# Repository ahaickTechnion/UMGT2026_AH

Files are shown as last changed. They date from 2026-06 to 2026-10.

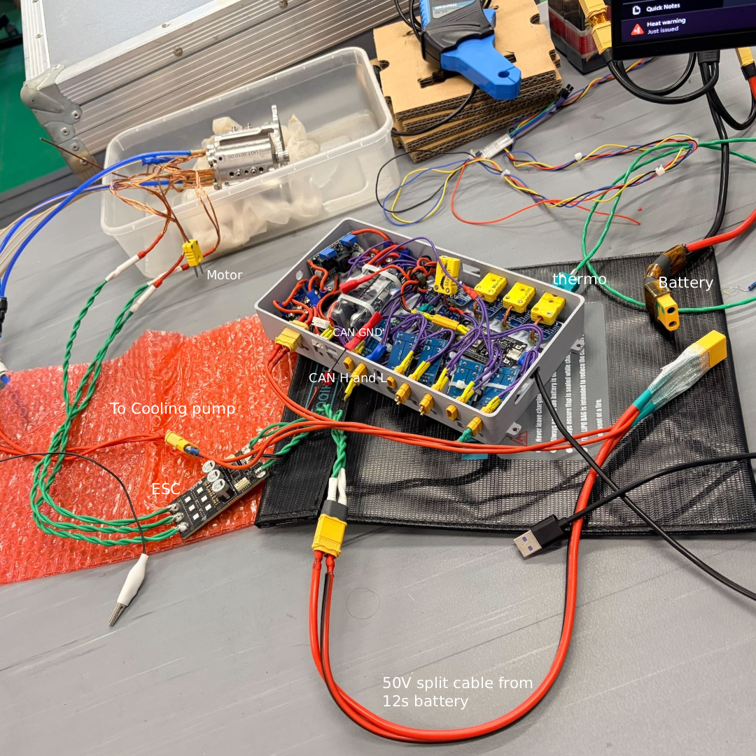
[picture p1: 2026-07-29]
UMGT/02. Documents/Motor setup.png

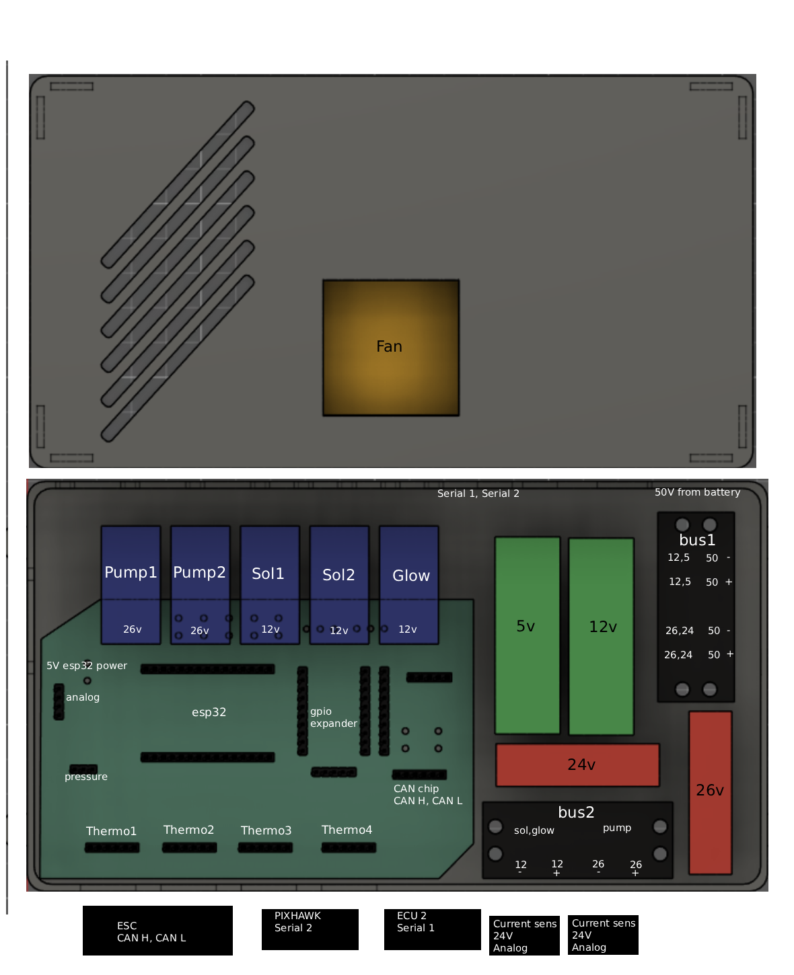
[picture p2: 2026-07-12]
UMGT/02. Documents/wiringdiagram2.png

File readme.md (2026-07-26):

# UMGT ECU 2026

ESP32 DevKitC-32 + ESPSheild carrier board. Firmware lives in `UMGT/src/main.ino.cpp`
(PlatformIO, `pio run -e esp32dev`). Two GUIs:

- `ecu_dashboard.py` → `dist/ECU_Dashboard.exe` — low-level I/O test bench
- `engine_dashboard.py` → `dist/UMGT_Engine.exe` — **engine-run GUI**, ported
  from the LabVIEW `umgt_7thJuly2026.vi` test stand (see `LABVIEW_ANALYSIS.md`)

Build either exe: `pyinstaller --onefile --windowed --name <Name> <file>.py`.

All pin assignments below are verified against the KiCad netlist
(`UMGT/ESPSheild-KiCAD/ESPSheild.kicad_pcb`).

---

## ESP32 Pin Summary (verified)

| GPIO | Net | Function |
|---|-----|---|
| GPIO1/3 | U0_TXD/U0_RXD | Serial 1 / USB console → EXE dashboard (J20) |
| GPIO2  | D2 | Extra I/O (J22) |
| GPIO4  | CRX  | **CAN RX** (SN65HVD230, J12) |
| GPIO5  | D5 | Extra I/O (J22) |
| GPIO12 | D12  | X9C digital pot **U/D** (J16) |
| GPIO13 | D13  | X9C digital pot **INC** (J16) |
| GPIO14 | D14  | Extra I/O (J22) |
| GPIO15 | D15  | Piezo / atomizer square wave (J19) |
| GPIO16 | U2_RXD | Serial 2 RX → Pixhawk (J21) |
| GPIO17 | U2_TXD | Serial 2 TX → Pixhawk (J21) |
| GPIO18 | SCK  | SPI clock (thermocouples) |
| GPIO19 | MISO | SPI MISO (thermocouples) |
| GPIO21 | SDA  | I2C data (PCF8575 expander @ 0x20) |
| GPIO22 | SCL  | I2C clock |
| GPIO23 | CTX  | **CAN TX** (no SPI MOSI on this board!) |
| GPIO25/26/27/32/33 | D25… | MOSFET PWM (J9, J10, J11, J7, J8) |
| GPIO34 | D34  | Analog: QNDB6 current sensor A (Battery) |
| GPIO35 | D35  | Analog: QNDB6 current sensor B (Load) |
| GPIO36/39 | VP/VN | Spare analog inputs (J24) |

## Thermocouples (MAX31855, SPI read-only)

Chip selects are **all on the PCF8575 expander** (active LOW).
Expander state bit = 8 + port number (P10 = bit 8 … P17 = bit 15).

| Connector | Net | Expander port | State bit | Channel |
|---|-----|---|---|---|
| J3 | CS1 | P12 | 10 | TC1 — TIT |
| J4 | CS2 | P13 | 11 | TC2 — EGT |
| J5 | CS3 | P14 | 12 | TC3 — Bearing |
| J6 | CS4 | P15 | 13 | TC4 — Coil |

## Digital pot (X9C103S/X9C503S, J16)

| J16 pin | Signal | Driven by |
|---|---|---|
| 1 | GND | — |
| 2 | U/D | GPIO12 |
| 3 | INC | GPIO13 (wiper steps on falling edge) |
| 4 | CS  | Expander P16 (state bit 14, active LOW) |
| 5 | 3.3V | — |

Firmware resets the wiper to position 0 at boot and tracks it 0–99.

## MOSFET outputs (J7–J11, 2-pin GND+signal)

Verified wiring (2026-07-08):

| # | Connector | GPIO | Load |
|---|---|---|---|
| 1 | J7  | 32 | **Glow plug** (on/off) |
| 2 | J8  | 33 | **Solenoid 2** |
| 3 | J9  | 25 | **Solenoid 1** |
| 4 | J10 | 26 | **Fuel pump 2** (KNF 1.4-M) |
| 5 | J11 | 27 | **Fuel pump 1** (KNF 1.4-M) |

PWM: LEDC channels 2–6 (piezo has channel 0 on its own timer), duty 0–10,
shared frequency default 10 kHz.

## CAN / ESC (SN65HVD230, J12 / passthrough J18)

TWAI driver, TX=GPIO23, RX=GPIO4, default **1 Mbps** (DroneCAN standard).
The ESC is a **Hargrave microDRIVE LPi speaking DroneCAN (UAVCAN v0)**.
Firmware decodes:

- `uavcan.equipment.esc.Status` (1034, 10 Hz, multi-frame): RPM, bus voltage,
  bus current, bridge temperature, power %, plus Hargrave's custom 13-bit
  error field (over-temp, over/under-volt, sig loss, saturation, etc.)
- `uavcan.equipment.esc.StatusExtended` (1036, 1 Hz): input/output %,
  motor temperature, status flags

Decoded values stream as `ESC_RPM/ESC_V/ESC_I/ESC_T/ESC_PWR/ESC_ERR/ESC_AGE/
ESC_IN/ESC_OUT/ESC_MT` keys and fill the ESC banner in the exe. `can esc`
prints them on demand with error names spelled out.

ESC control (all repeated at 50 Hz as node 100, array padded to the ESC's
reported index; `can stop` ends any mode with an explicit zero):

- `can duty <-100..100>` — duty cycle via `esc.RawCommand` (1030). Negative
  duty needs the ESC's **Reversible** drive mode (Normal mode clamps to 0).
- `can rpm <setpoint>` — closed-loop RPM via `esc.RPMCommand` (1031); the ESC
  clamps to its configured min/max RPM (needs correct pole-pair setting).
- `can brake <0-100>` — regen braking as negative duty (Reversible mode);
  braking torque is capped by the ESC's bus/phase current-limit settings.

The commanded mode/value streams back as `ESC_CMODE`/`ESC_CVAL` so the exe
always shows what is being commanded. The codec (Status, StatusExtended RX;
RawCommand, RPMCommand TX, negatives included) was verified bit-exact against
the reference `dronecan` python library.

The ECU is also a **dynamic node ID allocation server** (the role an autopilot
normally plays): an ESC with no node ID sends anonymous allocation requests,
the ECU collects its 16-byte unique ID over the 3-stage exchange and grants it
an ID (its preference, else 125). The ECU broadcasts its own NodeStatus at
1 Hz as node 100. Decoded NodeStatus heartbeats and anonymous-request counts
stream as `NS_ID/NS_MODE/NS_HP/NS_UP` and `ANON`, and the exe Bus tile shows
the allocation state (NO ID → NODE n → ESC OK). The allocation wire format
(echo + multi-frame CRC grant) was verified against pydronecan.

## Current sensors (QNDB6 hall, 100A / 5V output)

GPIO34 = Battery, GPIO35 = Load. Default calibration 20 A/V, zero at 0 V
(`current cal <zeroV> <A_per_V>` to adjust). Note: the ESP32 ADC clips at
~3.3 V ≈ 66 A unless a divider is added.

## Expander extra I/O

P00–P07 (state bits 0–7) are broken out on J13/J17 "EXTRA IO EXPAND" and are
controllable with `i2c expander bit <n> on|off`.

---

## Serial command set (115200 baud on USB)

```
status                          full status dump
tc read <1-4|all>               thermocouples (1=TIT 2=EGT 3=Bearing 4=Coil)
tc scan                         probe all 16 expander CS bits (find wiring/CS issues)
tc mode 31855|6675              select thermocouple chip decode
current all|a|b                 current sensors in amps
current cal <zeroV> <A_per_V>   calibration
pot pos|up <n>|down <n>|set <0-99>|reset|store
can [status|esc]                bus status + decoded microDRIVE telemetry
can duty <-100..100>            duty command (RawCommand 1030, 50 Hz)
can rpm <setpoint>              closed-loop RPM (RPMCommand 1031, 50 Hz)
can brake <0-100>               regen brake = negative duty (Reversible mode)
can stop                        stop any ESC command, send zero
can param list                  enumerate all ESC settings (99 on microDRIVE LPi)
can param get|set <NAME> [v]    by name — CASE-SENSITIVE (e.g. BUS_CUR_LIM)
can param geti|seti <idx> [v]   by index (typed automatically after a read)
can save                        persist ESC params to NVM (microDRIVE reboots itself)
can restart                     reboot ESC (clears latched ERROR flags)
can baud <125|250|500|1000> | can send <id> <hex bytes> | can print on|off
mosfet all|<1-5> on|off|duty <0-10>   ·   mosfet freq <hz>
piezo on|off|duty <0-255>|freq <hz>
analog all|vp|vn|a|b            raw ADC + volts
i2c scan | i2c expander set <hex> | i2c expander bit <n> on|off
serial2 send <text>             forward to Pixhawk UART
serial2 baud <rate>             change Serial2 baud (Pixhawk telem is usually 57600)
serial2 hex on|off              hex-dump Serial2 traffic (MAVLink is binary)
stream on|off                   telemetry stream (default 10 Hz)
stream rate <1-50>              stream rate in Hz; TCs sample at a fixed 10 Hz
                                (MAX31855 converts internally every ~100 ms)
```

### Engine control (ported from LabVIEW + designed sequencer)

```
eng start                       auto sequence: PRECHECK→GLOW→SPOOL→IGNITION→WARMUP→RUNNING
eng stop                        normal shutdown: fuel+glow off → COOLDOWN spin → OFF
eng abort | eng reset           immediate kill (latched FAULT) / clear fault
eng manual                      manual mode (direct pump/glow/throttle, failsafes live)
eng status | eng params         status dump / list parameters (PARAM:name=value)
eng set <name> <value>          edit any sequence/limit/PID parameter (live RAM)
eng save | eng defaults         persist params to ECU flash (survives reboot) / clear
gov on|off | gov sp <rpm>       RPM governor (NI PID Advanced form, out 15-100%)
gov gains <kc> <ti_min> <td_min>
thr <0-100>                     manual engine throttle (slew via governor off)
ramp up|down|pause|off          LabVIEW-style throttle ramp; ramp rate <pct/s>
pump <1|2> <0-100>              independent KNF fuel pumps, fine PWM; pump stop
glow on|off                     glow plug on MOSFET M1 (GPIO32)
sol <1|2> on|off                solenoid 1 (M3/GPIO25) / 2 (M2/GPIO33)
fuel cut on|off                 fuel shutoff latch (pumps forced to 0)
```

Failsafes (always active when anything is live, all editable):
TIT/coil/bearing over-temp, overspeed, flameout (lit + fuel + TIT below
floor), ESC telemetry loss, TIT thermocouple loss mid-sequence. Any trip →
everything safe + latched FAULT.

Engine stream keys: `ENG,FLT,GLW,P1,P2,FF,GOV,GSP,THR,FCUT,RMP`; state
transitions and faults print as `ENG:STATE=…` / `ENG:FAULT=…` events.

Actuators: glow=M1(32), sol2=M2(33), sol1=M3(25), pump2=M4(26), pump1=M5(27),
ESC=DroneCAN. Sensors: TC1=TIT, TC2=glow area, TC3=bearing, TC4=coil,
RPM/V/I from ESC.

Stream line format:

```
DATA:TC1=..,TC2=..,TC3=..,TC4=..,I_A=..,I_B=..,AVP=..,AVN=..,POT=..,PZF=..,PZD=..,CANRX=..,M1=..,..,M5=..
```

`HB` is emitted every second as a heartbeat; Pixhawk traffic is bridged to the
console as `[Serial2] …` lines.

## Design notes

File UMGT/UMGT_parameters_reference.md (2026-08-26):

# UMGT Engine Dashboard — Parameter Reference

Two completely separate sets of values reach this GUI, and mixing them up is the
single most common source of confusion:

| | **ECU internal values** | **ESC parameters** |
|---|---|---|
| Who owns them | the ESP32 (UMGT ECU) | the Hargrave microDRIVE LPi |
| How they arrive | `DATA:` stream, 10 Hz | DroneCAN request/response |
| Panel | *ECU Internal Values* | *ESC Parameters (DroneCAN)* |
| Read with | `Read` (from the last DATA frame) | `Get` → `can param get <NAME>` |
| Needs a working CAN bus | no | **yes** — dead while `CANRX=0` |

`THR` is an ECU value, not an ESC parameter. Asking the ESC for it over
DroneCAN gets no reply, because the ESC has never heard of it.

---

## 1. ECU internal values (the `DATA:` frame)

Sources: repo readme (pin table, MOSFET map, CAN section, engine stream keys)
and `_parse_data()` in `engine_dashboard.py`. Entries marked **(?)** are
inferred — the readme names the signal but not its exact semantics. Confirm
those against `UMGT/src/main.ino.cpp` before trusting them for anything
safety-related.

### Engine state machine

| Key | Unit | R/W | Meaning |
|---|---|---|---|
| `ENG` | — | R | Engine state: `OFF` / `PRECHECK` / `GLOW` / `SPOOL` / `IGNITION` / `WARMUP` / `RUNNING` / `COOLDOWN` / `FAULT` / `MANUAL`. Transitions also print as `ENG:STATE=…` |
| `FLT` | — | R | Latched fault code, `NONE` when clear. Set by the failsafes: TIT/coil/bearing over-temp, overspeed, flameout, ESC telemetry loss, TIT thermocouple loss. Clear with `eng reset` / RESET FAULT |
| `ARM` | — | R | ESC armed. `1` = the ESC will act on throttle. The microDRIVE refuses to spin without the arming broadcast |
| `FCUT` | — | R | Fuel-cut latch (`fuel cut on\|off`). `1` = both pumps forced to 0 regardless of demand |
| `RMP` | — | R | Throttle ramp machine: `OFF` / `UP` / `DOWN` / `PAUSE`, stepped at the ramp rate in %/s |

### Commanded outputs — writable

| Key | Unit | Write sends | Meaning |
|---|---|---|---|
| `THR` | % | `thr <v>` | Commanded engine throttle, 0–100 |
| `GOV` | — | `gov on` / `gov off` | RPM governor. `1` = the PID owns the throttle (output clamped 15–100 %) and `GSP` is the target |
| `GSP` | rpm | `gov sp <v>` | Governor RPM setpoint — only meaningful while `GOV=1` |
| `P1` | % | `pump 1 <v>` | Fuel pump 1 duty — KNF 1.4-M on M5 / GPIO27 |
| `P2` | % | `pump 2 <v>` | Fuel pump 2 duty — KNF 1.4-M on M4 / GPIO26 |
| `GLW` | — | `glow on` / `glow off` | Glow plug — M1 / GPIO32 |
| `SOL1` | % | `sol 1 on\|off` | Solenoid 1 — M3 / GPIO25 |
| `SOL2` | % | `sol 2 on\|off` | Solenoid 2 — M2 / GPIO33 |
| `FF` | ml/min | read-only | Fuel flow, derived from pump duty and the `pump1_cal` / `pump2_cal` parameters |

`THR`, `GSP`, `P1` and `P2` act on the engine immediately, so the GUI asks for
confirmation before sending.

### MOSFET raw duties

Duty is the raw LEDC value **0–10**, not a percentage. These are the same five
outputs as `GLW` / `SOL1` / `SOL2` / `P1` / `P2`, seen at the driver level.

| Key | Connector | GPIO | Load |
|---|---|---|---|
| `M1` | J7 | 32 | Glow plug |
| `M2` | J8 | 33 | Solenoid 2 |
| `M3` | J9 | 25 | Solenoid 1 |
| `M4` | J10 | 26 | Fuel pump 2 |
| `M5` | J11 | 27 | Fuel pump 1 |

In the frame you sent, `M3=10` — solenoid 1 sitting at full duty.

### Thermocouples (MAX31855, chip selects on the PCF8575 expander)

| Key | Connector | CS | Meaning |
|---|---|---|---|
| `TC1` | J3 | CS1 / P12 | Turbine inlet temperature (TIT), °C |
| `TC2` | J4 | CS2 / P13 | The readme's pin table calls this **EGT**, the engine section calls it **glow area** — same probe, two names |
| `TC3` | J5 | CS3 / P14 | Bearing temperature, °C |
| `TC4` | J6 | CS4 / P15 | Coil temperature, °C |

Instead of a number these read `nc` (no probe), `open` (open circuit) or
`sgnd` (shorted to ground). Your frame shows `TC1=nc`, `TC2=open`,
`TC3=open`, `TC4=sgnd` — no probes currently connected.

### ESC telemetry over DroneCAN

| Key | Unit | Source |
|---|---|---|
| `ESC_RPM` | rpm | `esc.Status` (1034, 10 Hz) |
| `ESC_V` | V | Bus voltage — also drives the battery % gauge |
| `ESC_I` | A | Bus current |
| `ESC_T` | °C | Bridge temperature |
| `ESC_PWR` | % | Power |
| `ESC_ERR` | — | Hargrave's custom 13-bit error field: over-temp, over/under-volt, signal loss, saturation… `can esc` spells the bits out |
| `ESC_AGE` | — | Age of the newest telemetry; rising means the stream stopped |
| `ESC_IN` | % | Input, from `esc.StatusExtended` (1036, 1 Hz) |
| `ESC_OUT` | % | Output, from StatusExtended |
| `ESC_MT` | °C | Motor temperature, from StatusExtended |
| `ESC_CMODE` | — | What the ECU is commanding: `DUTY` (RawCommand 1030), `RPM` (RPMCommand 1031), `BRAKE`, or `OFF` |
| `ESC_CVAL` | — | The value being sent in that mode, repeated at 50 Hz |
| `CANRX` | — | **Frames received from the ESC.** `0` = nothing arriving |

`CANRX=0` is the master switch for the whole ESC side: no telemetry, no
parameter access, no arming. Check bus wiring, 120 Ω termination at both ends,
bitrate (default 1 Mbps) and ESC power before anything else.

### DroneCAN node allocation

The ECU is the dynamic node-ID allocation server (node 100), the role an
autopilot normally plays.

| Key | Meaning |
|---|---|
| `NS_ID` / `NS_MODE` / `NS_HP` / `NS_UP` | Node ID, mode, health and uptime from a decoded NodeStatus heartbeat |
| `ANON` | Count of anonymous allocation requests — an ESC with no ID asking to be given one |

### Current sensors and analog inputs

| Key | Unit | Meaning |
|---|---|---|
| `I_A` | A | Current sensor **A — Battery**, GPIO34 |
| `I_B` | A | Current sensor **B — Load**, GPIO35 |
| `I_AV` **(?)** | V | Sensor A raw volts |
| `I_BV` **(?)** | V | Sensor B raw volts |
| `AVP` | V | Spare analog input **VP / GPIO36** (`analog vp`) |
| `AVN` | V | Spare analog input **VN / GPIO39** (`analog vn`) |

> **Discrepancy worth resolving.** The readme describes two independent QNDB6
> hall sensors on GPIO34/35 (20 A/V default, ADC clips near 66 A). The GUI's
> Current Sensor Cal panel and the comments in `_parse_data` instead describe a
> single Bourns SSA-2 differential shunt across the same two pins, where `I_AV`
> is the differential voltage and `I_BV` the common-mode (~1.44 V nominal =
> sensor alive). Both can't be right. Your frame shows `I_A` and `I_B`
> identical at −0.205 — consistent with the differential reading, not with two
> independent sensors. Worth confirming which board is fitted, because the
> calibration meaning of `current cal <zeroV> <A_per_V>` differs between them.

### Other on-board hardware

| Key | Unit | Meaning |
|---|---|---|
| `POT` | 0–99 | X9C digital pot wiper position. Reset to 0 at boot; stepped with `pot up\|down\|set` |
| `PZF` | Hz | Piezo / atomizer square-wave frequency — GPIO15 / J19 |
| `PZD` | 0–255 | Piezo / atomizer duty |
| `EXP` **(?)** | — | PCF8575 expander state. That expander also carries every thermocouple chip select, so a bad value here takes the TCs with it |
| `IFAIL` **(?)** | — | Peripheral failure counter, almost certainly the I2C/expander bus |
| `IREC` **(?)** | — | Peripheral recovery counter, paired with `IFAIL` |

> Your frame shows `IFAIL=510` with `IREC=0`. If that is an I2C error count
> that never recovered, it fits the four failed thermocouple reads —
> worth checking whether the expander at 0x20 answers `i2c scan`.

### Pixhawk / MAVLink bridge (Cube Orange, TELEM1 → J21 → Serial2)

| Key | Meaning |
|---|---|
| `PX_OK` | Heartbeat present. `1` = link up |
| `PX_SYS` / `PX_VER` | Autopilot system ID and MAVLink version |
| `PX_RAW` | **Raw bytes on the RX pin.** `0` = nothing wired or wrong baud (telemetry is usually 57600). Check this first |
| `PX_RX` | Messages successfully decoded |
| `PX_BAD` | Checksum failures — non-zero suggests baud mismatch or noise |
| `PX_TX` | Messages sent to the autopilot |
| `PX_HB` | Milliseconds since the last heartbeat |
| `PX_FIX` | GPS fix: 0 none, 1 no fix, 2 = 2D, 3 = 3D, 4 DGPS, 5 RTK float, 6 RTK fixed, 8 static |
| `PX_SATS` | Satellites used in the fix |
| `PX_HDOP` | Horizontal dilution of precision — under 2.0 is healthy |

---

## 2. Engine parameters (`eng params`)

These are the ECU's editable settings — the table on the Engine page, and also
readable and writable by name from the ECU Internal Values panel. They arrive
as `PARAM:name=value` lines in response to `eng params`.

- **Write** sends `eng set <name> <value>`, which changes live RAM only.
- **Save to ECU** then issues `eng save`, which persists to ESP32 flash.
- `eng defaults` clears them back to firmware defaults.

They cover the start sequence (glow temperature and time, spool duty/RPM and
timeout, ignition fuel start/ramp/max, light-off TIT, ignition timeout, warmup
idle RPM), the failsafe limits (TIT/coil/bearing maxima, max RPM, flameout TIT
floor, ESC loss timeout), cooldown behaviour, pump and fuel calibration,
governor PID gains and limits, ramp rate, and battery voltage endpoints. The
full list with labels and units is `PARAM_META` at the top of
`engine_dashboard.py`.

---

## 3. ESC parameters (DroneCAN)

**I can't give you a per-parameter table for these, and I'd be inventing it if
I tried.** The names live inside the Hargrave microDRIVE LPi's own firmware,
not in this repository — the readme only tells us there are about 99 of them
and gives `BUS_CUR_LIM` as an example. Nothing in `engine_dashboard.py`
enumerates them either; the GUI just passes names through to the ECU.

What is documented:

| Button | Command | Notes |
|---|---|---|
| Get | `can param get <NAME>` | Names are **CASE-SENSITIVE** — `BUS_CUR_LIM`, not `bus_cur_lim` |
| Set | `can param set <NAME> <value>` | Live only until saved |
| List all | `can param list` | Enumerates the real set — the only authoritative source |
| Save NVM | `can save` | Persists to the ESC; **the microDRIVE reboots itself afterwards** |
| Restart ESC | `can restart` | Reboots the ESC and clears latched ERROR flags |

The firmware also supports access by index — `can param geti|seti <idx>` —
which the ECU types automatically after a read.

Two constraints worth remembering: nothing in this panel works while
`CANRX=0`, and changes are lost on an ESC power-cycle unless you Save NVM.

**If you run List all and paste the output to me, I'll document every one of
them properly and add the descriptions to the GUI's help.**

---

## In-app help

Both panels now have a **?** button.

- *ECU Internal Values* — with a name in the box, `?` prints that key's
  description, unit and whether it's writable. With the box empty it prints
  the whole table for the keys in the current DATA frame. `Read` also prints a
  one-line reminder under the value.
- *ESC Parameters* — `?` prints how DroneCAN parameter access works and what
  each button sends.

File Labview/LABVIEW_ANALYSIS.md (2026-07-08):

# LabVIEW `umgt_7thJuly2026.vi` — reverse-engineering notes

Extracted with pylabview from `UMGT/Labview/7thJuly2026/D/!!!Main - Alicat MFC
and pwmESC Folder_1/umgt_7thJuly2026.vi` (front panel heap, block diagram
heap, link info). This is the spec for the ECU engine firmware + engine exe.

## What the VI actually is

A **manual turbogenerator test-stand GUI** — parallel while-loops, no
automated start/stop state machine. The operator manually ramps the ESC,
enables fuel, and watches gauges. Sequencing/failsafes must be designed new
for the ECU (they do not exist in the LabVIEW).

## Front panel — engine-relevant controls (with LabVIEW labels)

Readouts:
- Turbine Inlet Temperature [K] — with color-box warning thresholds
- Near Glow plug Temperature [K] — color thresholds
- Bearing Temperature [degC]
- Generator Coil Temperature [degC] — color thresholds
- Shaft Speed [RPM] (from "MotorTone" tone-frequency measurement)
- DC Voltage [V], DC Current [A], DC Power [W], Battery % (color-coded,
  min/max scaling switched by the 1500 W / 300 W mode)
- Compressor Outlet Pressure [Pa] (transducer: P = 16000*V),
  Inlet Pressure Delta [Pa], Atmospheric Pressure, Bias Voltage
- Air Flow Rate [g/s], Propane Fuel Flow Rate [g/s], total fuel flow, p+k
- Equivalence ratios: Overall Eq Ratio, Equivalence Ratio propane,
  Required Eq Ratio Propane, Required Eq Ratio Kero,
  Required Propane Fuel Flow Rate, Propane Flow Rate Setpoint
- Elapsed Time
- Graphs: RPM, Generator Power, Pressure Ratio, Coil Temperature,
  Bronkhorst Flow rate, KNF Pump flow rate, Dispensed Volume (x2)

Controls:
- speed slider (manual ESC throttle), STOP MOTOR, Stop - Actual, STOP CODE
- Ramp Up / Pause / Ramp Down buttons, Ramp Rate [%/sec], Ramp time,
  Max RPM, Ramping mode indicator
- PID CONTROL toggle + PID gains cluster (Kc, Ti min, Td min) + "PID SETP"
- Fuel Shut Off, Track Fuel Flow Rate
- 1500 W / 300 W mode toggle
- Record, save file (CSV logging via Write Delimited Spreadsheet)
- Time to wait [ms] (loop pacing), HT/LT/full (PWM pulse times)
- Tank 3 / Tank 4 level sliders (syringe pumps), RUN/PAUSE pump buttons

Rig hardware being replaced/dropped in the ECU port:
- Alicat MFC (propane), Bronkhorst FLOW-BUS (kero flow), NE-50X syringe
  pumps, DAQmx AI (temps/pressures), DAQmx CO pulse (ESC PWM), SIMLAB PSU.

## Block diagram logic decoded

- **ESC drive**: Throttle % → "% to us" → 1500..2000 µs servo pulse
  ("2000us (full with)", HT/LT counter times), with a slew limiter
  ("limiting to avoid glitching"). ECU equivalent: DroneCAN duty command.
- **PID**: NI `PID Advanced.vi` — enabled by PID CONTROL; gains from the
  cluster; dt (s) from the loop; **output clamped 15%..100% throttle**;
  setpoint wire labeled "PID SETP"; PV is the measured shaft RPM
  (MotorTone), i.e. an RPM governor commanding ESC throttle.
- **Ramping mode**: case machine driven by Ramp Up/Pause/Ramp Down with
  Ramp Rate [%/s] / Ramp time / Max RPM.
- **Air mass flow**: formula node `mdot = 0.702*sqrt(Pin)` for 1500 W mode,
  0.54 for 300 W (comment: "change mdot from 0.702 for 1500W to 0.54 for
  300W"); Pin = compressor outlet pressure.
- **Fuel stoichiometry**: propane AFR constant 15.5 ("changed from 15.67 to
  15.5"); kero AFR separate; required fuel flow = f(target eq ratio, mdot).
  "Track Fuel Flow Rate" makes the fuel setpoint follow the requirement;
  **Fuel Shut Off forces the fuel flow setpoint to zero**.
- **Kero conversion**: ml/min → g/s via density 0.84 ("ml/min to g/s
  (0.84/60)").
- **Pressure cal**: `P = 16000*V`.
- **Warning colors**: case structures recolor TIT / glow-plug temp / coil
  temp / Battery % indicators against thresholds (thresholds live in the
  unparsed dataspace — re-specified as config in the ECU port).
- **Stop - Actual**: user dialog + loop stop. STOP MOTOR zeroes throttle.

## Mapping to the ECU (per Owen's instructions)

| LabVIEW | ECU |
|---|---|
| ESC PWM 1500-2000 µs + MotorTone RPM | DroneCAN duty + esc.Status RPM/V/I/temp |
| DC V/I/P, Battery % | ESC telemetry voltage/current, computed power |
| NE-50X + Bronkhorst + Alicat fuel | 2× KNF 1.4-M pumps on MOSFET PWM (M1, M2?) |
| Glow plug (external PSU, temp readout only) | Glow plug on/off on MOSFET M5 |
| DAQmx thermocouples | 4× MAX31855: TIT, glow-area (EGT), bearing, coil |
| Pressure transducers | not fitted (VP/VN spare analog if added later) |
| 2 solenoids | not in LabVIEW; ECU has M3/M4 spare |
| PID Advanced (RPM→throttle 15-100%) | Same PID on ESP32, gains from exe |
| Manual ops only | + designed auto start/shutdown/failsafe state machine |

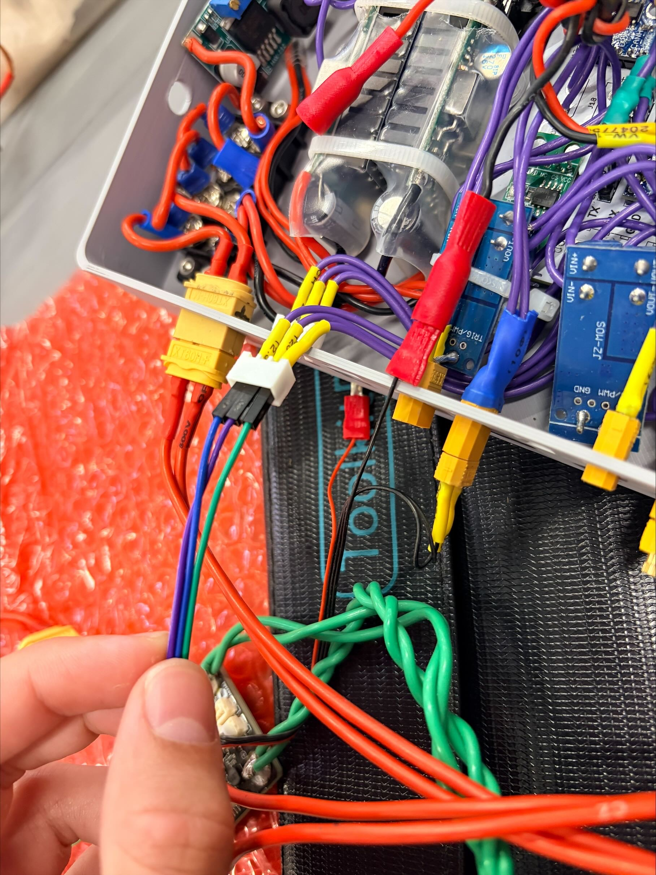
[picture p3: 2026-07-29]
UMGT/02. Documents/Serial Connection.png

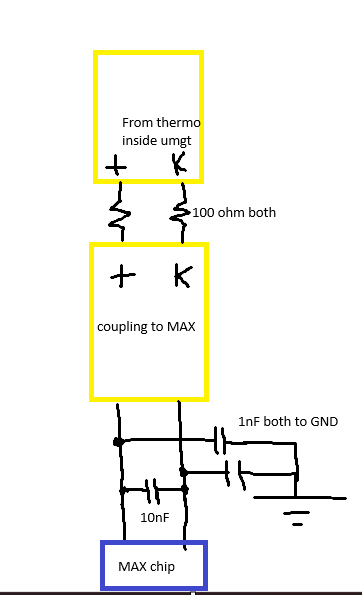
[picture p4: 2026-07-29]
UMGT/02. Documents/MAX chip denoise Diagram.png

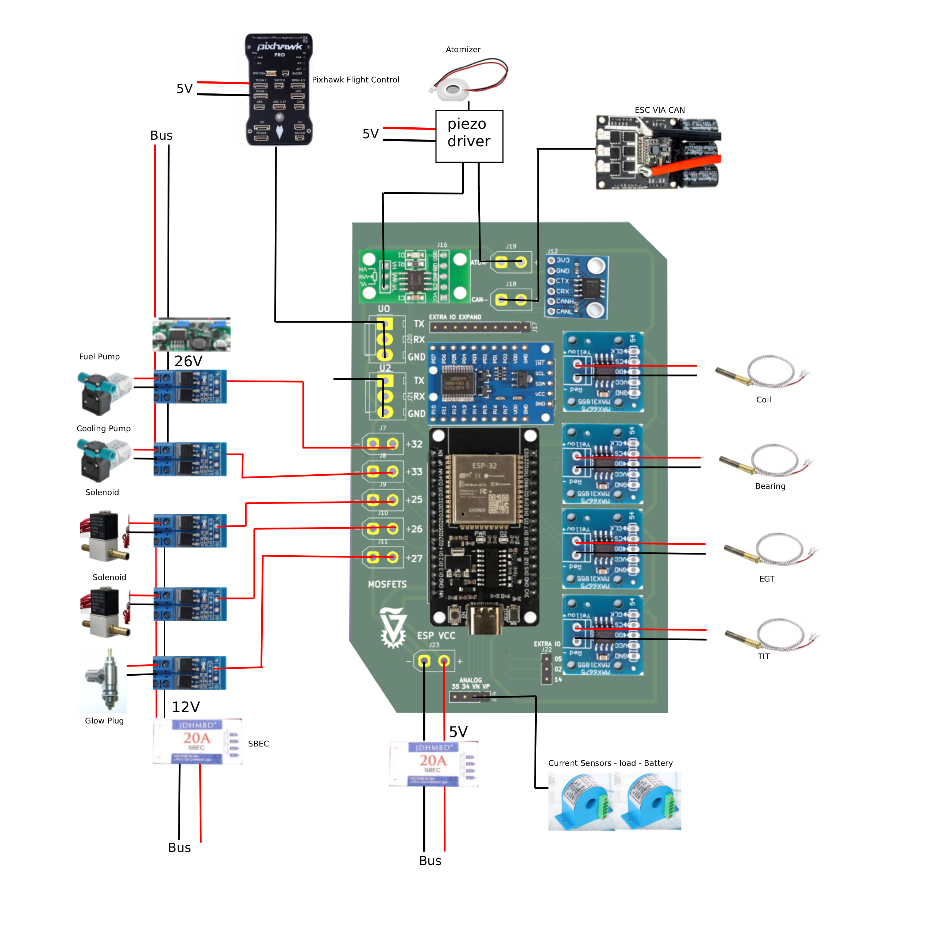
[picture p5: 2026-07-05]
UMGT/02. Documents/Full layout.png

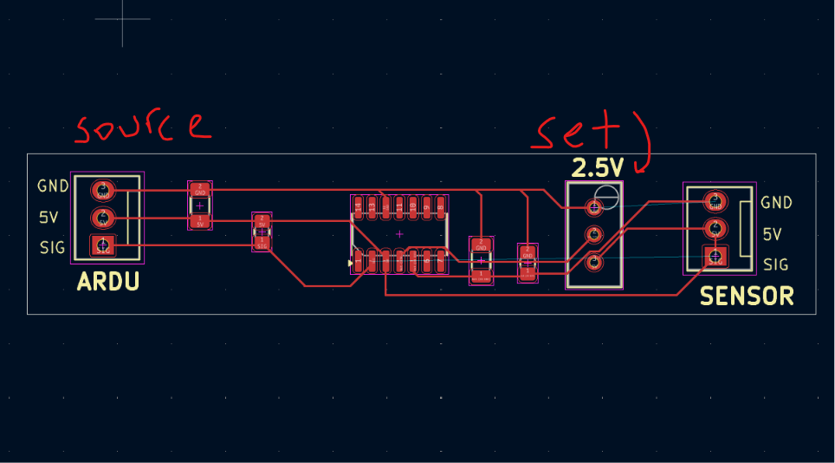
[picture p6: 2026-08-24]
UMGT/00. PCB Boards/RPMSENSOR/sensordiagram1.png

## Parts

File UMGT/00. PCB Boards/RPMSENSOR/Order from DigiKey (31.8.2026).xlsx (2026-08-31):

DigiKey - Shopping Cart
Index | Quantity | Part Number | Manufacturer Part Number | Description | Unit of Measure | Customer Reference | Available | Backorder | Unit Price | Extended Price ILS
1 | 50 | 900-0022013037-ND | 0022013037 | CONN RCPT HSG 3POS 2.54MM |  |  | 50 | 0 | 0.283 | 14.15
2 | 12 | 4518-LM339DRCT-ND | LM339DR | IC COMPARATOR 4CH 14-SOP |  |  | 12 | 0 | 0.437 | 5.24
3 | 12 | 296-1013-1-ND | LM339DR | IC COMPARATOR 4CH 14-SOIC |  |  | 12 | 0 | 0.647 | 7.76
4 | 25 | 311-2.00KCRCT-ND | RC0805FR-072KL | RES 2K OHM 1% 1/8W 0805 |  |  | 25 | 0 | 0.084 | 2.10
5 | 25 | 311-1.00MCRCT-ND | RC0805FR-071ML | RES 1M OHM 1% 1/8W 0805 |  |  | 25 | 0 | 0.084 | 2.10
6 | 25 | 1276-1050-1-ND | CL31B102KBCNNNC | CAP CER 1000PF 50V X7R 1206 |  |  | 25 | 0 | 0.22 | 5.50
7 | 25 | 1276-1017-1-ND | CL31B104KBCNNNC | CAP CER 0.1UF 50V X7R 1206 |  |  | 25 | 0 | 0.22 | 5.50
8 | 12 | 3296W-103LF-ND | 3296W-1-103LF | TRIMMER 10K OHM 0.5W PC PIN TOP |  |  | 12 | 0 | 6.532 | 78.38
9 | 50 | WM4112-ND | 0022272031 | CONN HEADER VERT 3POS 2.54MM |  |  | 50 | 0 | 0.65 | 32.50
10 | 100 | WM1114CT-ND | 0008500113 | CONN 22-30AWG CRIMP TIN |  |  | 100 | 0 | 0.1572 | 15.72
11 | 100 | WM2312-ND | 0008550102 | CONN 22-30AWG CRIMP GOLD |  |  | 100 | 0 | 0.3797 | 37.97

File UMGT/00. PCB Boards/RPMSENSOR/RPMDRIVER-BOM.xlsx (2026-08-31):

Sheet: BOM
Ref | Value | Package / footprint (measured from Gerbers) | Manufacturer | Manufacturer part no. | Qty per board | Qty to order | Notes
U3 | LM339 | SOIC-14, 1.27mm pitch, 3.9mm body | Texas Instruments | LM339DR | 1 | 2 | Quad comparator, open-collector out. Input common-mode range excludes top ~1.5V below V+.
R1 | 2k | 0805 (pads 1.20x1.40mm, 2.00mm centres) | Yageo | RC0805FR-072KL | 1 | 10 | Pull-down on sensor input at U3 pin 5. 1%, 1/8W.
R2 | 1M | 0805 (pads 1.20x1.40mm, 2.00mm centres) | Yageo | RC0805FR-071ML | 1 | 10 | Pull-up on open-collector output. Consider 10k (RC0805FR-0710KL) instead.
C1 | 1nF | 1206 (pads 1.15x1.80mm, 2.95mm centres) | Samsung | CL31B102KBCNNNC | 1 | 10 | Filter on sensor input. 50V X7R; C0G preferred if available.
C2 | 100nF | 1206 (pads 1.15x1.80mm, 2.95mm centres) | Samsung | CL31B104KBCNNNC | 1 | 10 | Supply decoupling at U3. 50V X7R.
RV1 | 10k | Multiturn trimmer, 9.77x5.07mm body, 3 pins in-line 2.54mm, 0.8mm drill | Bourns | 3296W-1-103LF | 1 | 2 | Full divider across 5V/GND, wiper sets threshold. Any value gives 2.5V mid-travel; 10k draws 0.5mA.
J1, J3 | - | 3-pin header 2.54mm, 1.02mm drill, oval pads 2.03x1.73mm, body 7.80x6.05mm | Molex | 22-27-2031 | 2 | 4 | KK-254 friction-lock vertical header. A plain 1x3 2.54mm pin header also fits the holes.
- | - | Mating housing for J1/J3 | Molex | 415304 | 2 | 4 | KK-254 3-circuit crimp housing, one per cable end.
- | - | Crimp terminal for housing | Molex | 08-50-0114 | 6 | 12 | KK-254 female crimp terminal, 3 per housing.
Total lines to order: |  |  |  |  | 16 | 64

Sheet: Board info
Item | Detail
Project | RPMDRIVER (KiCad 8.0.8, gerbers dated 2026-05-20)
Board outline | 73.10 x 14.88 mm, 2 layers, no vias
Drill sizes | 0.80 mm (RV1), 1.02 mm (J1, J3) - both plated
Nets | GND, +5V, sensor (J3.3 -> U3.5), threshold (RV1.2 -> U3.4), SIG (U3.2 -> R2 -> J1.1)
Unused | U3 pins 1, 6, 7, 8, 9, 10, 11, 13, 14 are N/C - three comparators unconnected
Source of values | R1, R2, C1, C2 values come from the schematic, not from the gerbers
Source of packages | Measured from pad apertures, drill file and silkscreen outlines
Open item | J3 has no ground pin: pins 1 and 2 are both on +5V, pin 3 is the sensor signal
Open item | Pad net tags disagree with trace net tags at J3 - PCB rerouted, schematic not updated

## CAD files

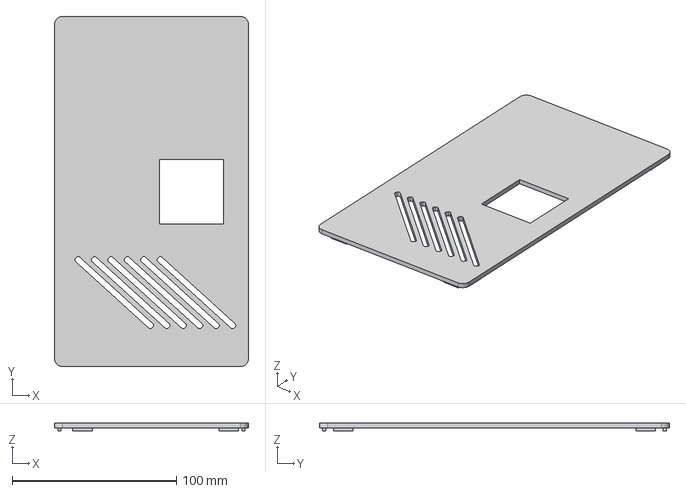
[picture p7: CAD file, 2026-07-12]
UMGT/04. CAD/Owen's Version/BoxtopIGES.iges
118.0 x 213.0 x 5.00 mm

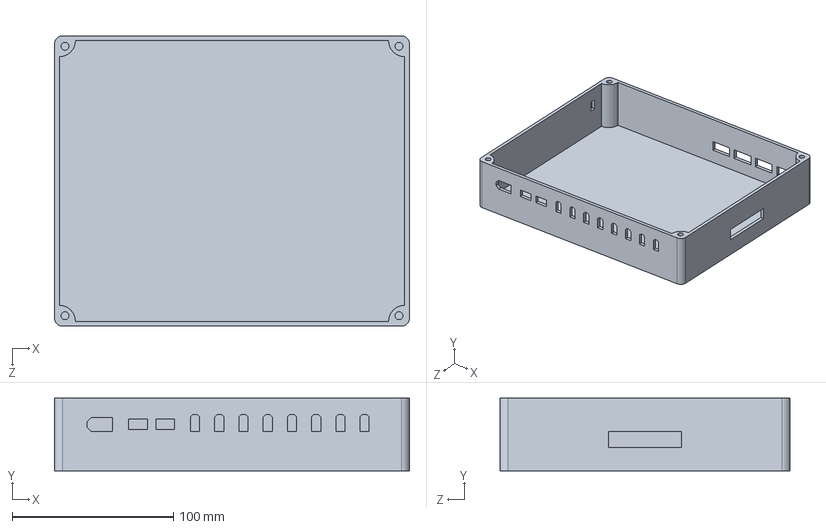
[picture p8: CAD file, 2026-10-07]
UMGT/04. CAD/UMGT-Box-2.SLDPRT
220.0 x 45.0 x 180.0 mm

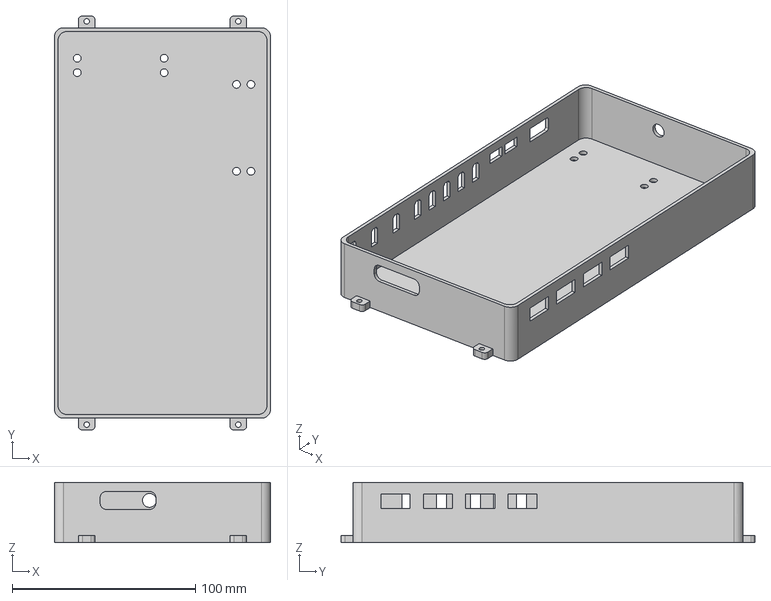
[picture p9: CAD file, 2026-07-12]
UMGT/04. CAD/Owen's Version/BoxbottomIGES.iges
118.0 x 225.9 x 33.0 mm

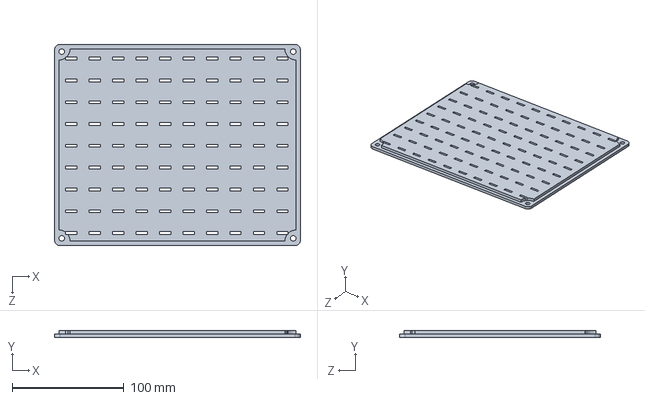
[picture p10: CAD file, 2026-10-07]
UMGT/04. CAD/UMGT-Cover-2.SLDPRT
220.0 x 6.00 x 180.0 mm

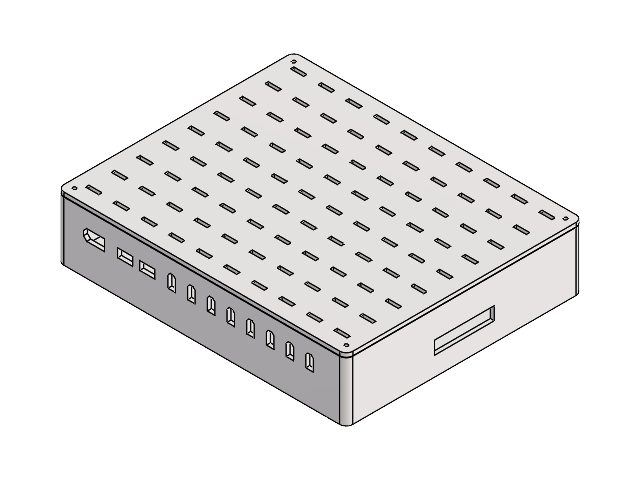
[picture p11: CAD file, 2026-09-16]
UMGT/04. CAD/Assem1.SLDASM
UMGT-Box-2
UMGT-Box-2.2

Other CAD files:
UMGT/04. CAD/UMGT-Box-1.SLDPRT
UMGT/04. CAD/UMGT-Box-2.STL
UMGT/04. CAD/UMGT-Cover-2.STL

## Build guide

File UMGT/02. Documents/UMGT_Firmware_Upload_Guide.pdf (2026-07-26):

UMGT ECU — Firmware Upload Guide | Page 1

# UMGT ECU — Firmware Upload Guide

How to build and upload the ESP32 firmware with PlatformIO

The ECU's brain is an ESP32 board. Everything it does — reading thermocouples, driving pumps, talking to the ESC and Pixhawk — is one program (the firmware) held in a single source file. To change how the ECU behaves you edit that file, build it (compile it on the PC), then upload it to the board over USB. This guide covers exactly that, start to finish. No coding knowledge required — just the steps.

You will need
- The ECU (the ESP32 board on the shield)
- A USB-C data cable (not a charge-only cable)
- A Windows PC with PlatformIO installed (see Section 2)

## 1 Connect the ECU to the computer

The ESP32 board has a USB-C connector on its short edge. Plug USB-C into the ESP32 and the other end into the PC. Power the shield as usual; the USB link is only for programming and the serial console.
- Use a data cable. Many USB cables carry power only — the board will light up but never appear on the PC. If nothing shows up, suspect the cable first.
- The board uses a CH340 USB-to-serial chip. Windows assigns it a COM port number, e.g. COM4 or COM5. You'll need that number.
- If no COM port ever appears, install the CH340 driver (search “CH340 driver Windows”), unplug and replug.

Close the dashboard first
A COM port can only be owned by one program at a time. If the UMGT Engine dashboard (or any serial monitor) is Connected to the board, the upload will fail with “port is busy”. Click Disconnect in the dashboard before uploading — you do not have to close the whole app.

## 2 Set up PlatformIO (one-time)

PlatformIO is the free tool that compiles the code and flashes it to the board. There are two ways to use it — pick one.
Option A — Visual Studio Code (recommended, has buttons)
1 Install Visual Studio Code (free, from Microsoft).
2 Open VS Code → click the Extensions icon on the left (four squares) → search PlatformIO IDE → Install.
3 Let it finish downloading its toolchain, then restart VS Code when it asks. A small PlatformIO (alien head) icon and a blue bottom toolbar appear when it's ready.

Option B — Command line (already installed on this PC)

PlatformIO Core is already installed here, so you can skip Option A if you prefer typing commands. The program is:

C:\Users\owen.maute\.platformio\penv\Scripts\pio.exe

If you type pio in a terminal and it says “not recognized”, use that full path in place of pio in every command below. To install PlatformIO Core on another PC: pip install platformio.

## 3 Where the files live

Everything for the ECU is in the project repo. Two files matter for uploading:

Item | Location / value
Repo root | C:\Users\owen.maute\UMGTECU2026
PlatformIO project | ...\UMGTECU2026\UMGT
Firmware source (edit this) | ...\UMGT\src\main.ino.cpp
Build config | ...\UMGT\platformio.ini

Open the right folder
In VS Code use File → Open Folder and open the UMGT folder — the one that directly contains platformio.ini. If you open the repo root or the wrong level, PlatformIO won't recognise the project and the Build/Upload buttons won't appear.

main.ino.cpp is the entire ECU program — the pin map, the thermocouple/ESC/Pixhawk code, the start sequence, all of it. It is the only file you edit to change behaviour.
platformio.ini tells PlatformIO which board and port to use. It currently reads:

[env:esp32dev]
platform = espressif32
board = esp32dev
framework = arduino
monitor_speed = 115200
upload_speed = 115200
monitor_port = COM4
upload_port = COM4

The only line you may need to change is upload_port (and monitor_port) — see Section 6 on picking the right COM number.

## 4 Verify (build/compile) the code

Always build before you upload. Building compiles the code on the PC and catches mistakes there — a typo caught on the PC is harmless; the same typo flashed to the board could leave the ECU dead. Building does not touch the board, so it's completely safe to do anytime.
In VS Code:
- Click the checkmark (✓) in the blue bottom toolbar, or
- open the PlatformIO sidebar → esp32dev → General → Build.

On the command line (from inside the UMGT folder):

cd C:\Users\owen.maute\UMGTECU2026\UMGT
pio run -e esp32dev
A good build ends with a green SUCCESS and a memory summary like:

RAM: [= ] 7.2% (used 23592 bytes ...)
Flash: [=== ] 28.7% (used 376529 bytes ...)
==================== [SUCCESS] Took 8.0 seconds ====================
If instead you get errors, PlatformIO prints each one with the file and line number (e.g. main.ino.cpp:1234: error: ...). Nothing was sent to the board. Fix the line, build again, repeat until it says SUCCESS.

## 5 Upload to the ECU

Once the build is SUCCESS and the dashboard is disconnected, flash it: In VS Code:
- Click the right-arrow (→) in the blue bottom toolbar, or
- PlatformIO sidebar → esp32dev → General → Upload.

On the command line:

pio run -e esp32dev -t upload
If the board is on a different COM port than platformio.ini lists, name it explicitly (nothing else needs to change):

pio run -e esp32dev -t upload --upload-port COM5
A successful upload scrolls through these stages:
- Connecting........
- Writing at 0x00010000... (12%) … climbing to 100%
- Hash of data verified.
- Hard resetting via RTS pin...

Hash of data verified plus Hard resetting means it worked — the ECU reboots straight into the new firmware. You can reconnect the dashboard now.

## 6 Picking the right COM port

This is the most common gotcha
The ESP32 does not always keep the same COM number. It may come up as COM4 one time and COM5 the next — especially after unplugging and replugging. platformio.ini is set to COM4, but the board is often on COM5. When in doubt, check.

Find the current port two ways:
- Device Manager → Ports (COM & LPT) → look for USB-SERIAL CH340 (COMx). That COMx is your board.

- Or list it from PlatformIO: pio device list.

Then either edit the two ...port = COMx lines in platformio.ini, or just pass --upload-port COMx on the command line for a one-off. (COM1 is not your board — that's a built-in port; ignore it.)

## 7 Troubleshooting

Symptom | Fix
“Could not open COMx, the port is busy” | The dashboard or a serial monitor owns the port. Disconnect it, then upload.
“Failed to connect” / “Timed out waiting for packet header” | Hold the BOOT button on the ESP32 while it says Connecting......, release once Writing starts. Also try a different USB port or cable.
No COM port appears at all | Charge-only cable, or the CH340 driver isn't installed. Swap to a data cable / install the driver, then replug.
Wrong port / uploads to nothing | Board re-enumerated to a different COM number — see Section 6, pass --upload-port.
Build fails with red errors | A code mistake — nothing was flashed. Fix the file:line it names and build again.
Uploads OK but the ECU misbehaves | Confirm you actually edited UMGT\src\main.ino.cpp and that the build was SUCCESS before uploading.
Board keeps dropping off USB mid-session | Usually a power/grounding issue on the rig rather than software — reseat power and USB, avoid unpowered USB hubs.

## 8 Quick reference

Command-line cheat sheet (run these from inside the UMGT folder):

Do this | Command
Go to the project | cd C:\Users\owen.maute\UMGTECU2026\UMGT
Build / verify | pio run -e esp32dev
Upload | pio run -e esp32dev -t upload
Upload to a specific port | pio run -e esp32dev -t upload --upload-port COM5
List connected boards | pio device list
Open the serial console | pio device monitor -b 115200
Clean build files | pio run -e esp32dev -t clean

Golden rule: Disconnect the dashboard → Build (✓) → Upload (→) → wait for “Hash of data verified”.

UMGT ECU project — firmware upload guide. Source of truth: UMGT\src\main.ino.cpp and UMGT\platformio.ini.

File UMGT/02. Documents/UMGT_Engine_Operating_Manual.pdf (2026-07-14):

UMGT Engine Control — Operating Manual | Page 1

# UMGT Engine Control

## Operating Manual & Reference

## Micro gas-turbine ECU — ESP32 firmware + UMGT_Engine dashboard

This manual describes how to connect, configure and operate the UMGT turbine engine control system: every panel, button, parameter and serial command in the UMGT_Engine application, the automatic start sequence, the failsafe logic, and the ESC / fuel / sensor subsystems.

Generated for the UMGT ECU 2026 project

# 1. System Overview

The UMGT engine control system has two halves that talk to each other over a single USB serial link:

■ The ECU (firmware) — an ESP32 DevKitC-32 on a custom carrier board ("ESPSheild"). It reads the sensors, drives the actuators, runs the automatic start/shutdown sequence, the RPM governor and all failsafes, and talks to the ESC over a DroneCAN bus.
■ UMGT_Engine.exe (the GUI) — a Windows dashboard that connects to the ECU over USB, shows live telemetry (charts and gauges), and lets you command the engine, tune parameters and log data. It is a monitor and controller only — all real-time control happens on the ECU, so the engine stays safe even if the PC or USB link drops.
The GUI is modeled on the original LabVIEW turbine test-stand, extended with an automatic sequencer and failsafe supervisor that the LabVIEW did not have.

## 1.1 What the ECU controls and reads

Function | Hardware | Notes
ESC / starter-generator | Hargrave microDRIVE LPi over DroneCAN (CAN 1 Mbps) | Throttle, RPM, brake; reads RPM / voltage / current / temperature
Fuel pump 1 | MOSFET M5 (GPIO27), Hausl ZP25M14F gear pump | PWM, ml/min via calibration curve
Fuel pump 2 | MOSFET M4 (GPIO26) | Independent second fuel pump
Glow plug | MOSFET M1 (GPIO32) | On/off ignition heater
Solenoid 1 | MOSFET M3 (GPIO25) | PWM to ~6 V (configurable duty)
Solenoid 2 | MOSFET M2 (GPIO33) | PWM to ~6 V (configurable duty)
Thermocouples x4 | MAX31855 (SPI), CS via PCF8575 I2C expander | TC1 TIT, TC2 EGT, TC3 Bearing, TC4 Coil
Current sensors x2 | QNDB6 hall sensors on GPIO34 / GPIO35 | Battery / load current
Pixhawk link | Serial2 (GPIO16/17) | Optional telemetry bridge

## 1.2 The USB data link

The ECU streams a compact DATA: line at up to 50 Hz (default 10 Hz) carrying every live value, plus a one-per-second HB heartbeat so the GUI always knows the ECU is alive even when streaming is off. Commands are plain text typed or sent as button presses.

NOTE: The GUI enables the stream automatically when you connect. If you ever see the heartbeat but no live data, type stream on in the terminal — the board is fine, the stream was just off.

# 2. Getting Started

## 2.1 Connecting

1 Plug the ESP32 into USB. Launch UMGT_Engine.exe.
2 Pick the COM port from the drop-down (top-right). If unsure, click the refresh arrow and choose the CH340 port.
3 Click Connect. The ESP32 reboots (~2 s), then the status turns green “Connected” and data begins to flow.
4 Within a few seconds the GUI pulls the saved parameters from the ECU into the parameter panel.

NOTE: The USB-serial port number can change between plug-ins (COM4/COM5/etc.). Just pick whichever port appears. If none appears, unplug and replug the ESP32's USB cable.

## 2.2 The header bar

The header bar, left to right: (1) engine-state chip, (2) COM port, (3) Connect, (4) Record, (5) ABORT ALL.

Control | What it does
Engine state chip | Large label showing the current sequencer state (OFF, MANUAL, PRECHECK, GLOW, SPOOL, IGNITION, WARMUP, RUNNING, COOLDOWN, FAULT).
FAULT text | Appears in red next to the state when a failsafe has tripped, naming the fault.
t = <n> s | Seconds since connecting.
Port drop-down + refresh | Select / rescan the serial port.
Connect / Disconnect | Open or close the serial link.
Record | Start/stop CSV logging of every telemetry field to a file you choose.
ABORT ALL | Emergency stop — immediately cuts fuel, glow, throttle and disarms the ESC, latching a FAULT. Always available.

WARNING: The ABORT ALL button (and the eng abort command) is your emergency stop. It kills every actuator instantly. Know where it is before running the engine.

# 3. The Dashboard, Panel by Panel

The window is arranged in three columns. The left column holds the live charts and the engine-data gauges; the middle column holds the ESC/throttle and fuel controls; the right column holds the sequencer, the parameter editor, the ESC parameter tool and the event terminal.

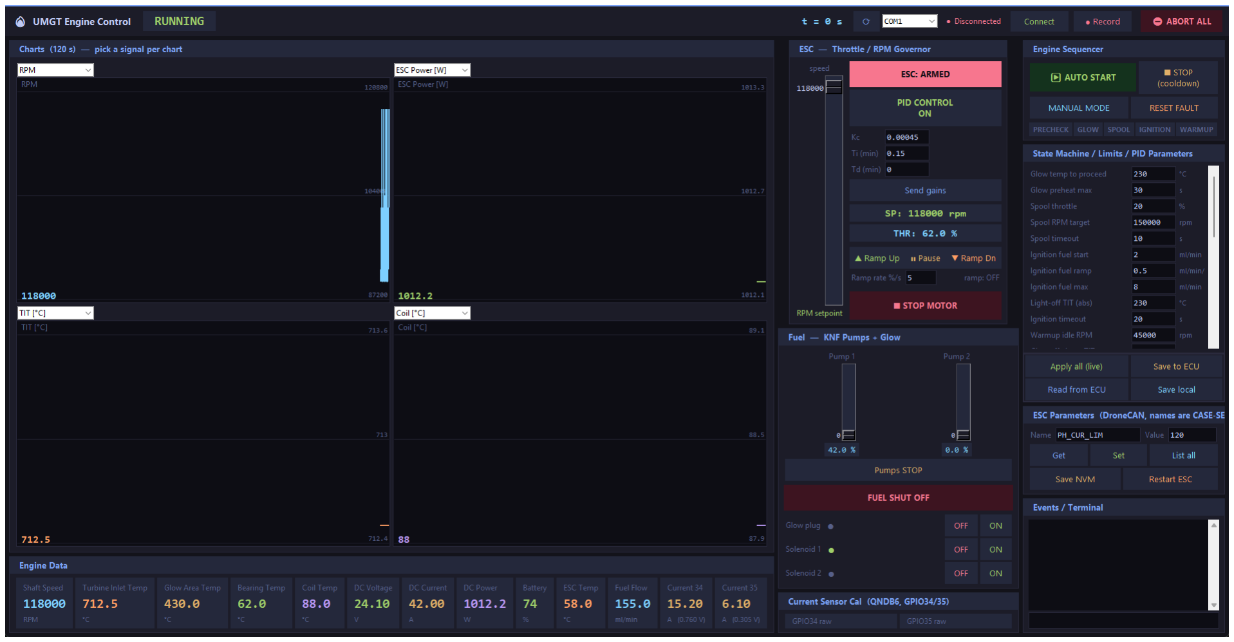
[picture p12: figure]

The full UMGT_Engine dashboard (shown with simulated running data). Left: charts + engine-data gauges. Middle: ESC/throttle and fuel. Right: sequencer, parameters, ESC parameters, terminal.

## 3.1 Charts (top-left)

Four strip charts scroll the last 120 seconds. Each chart has a drop-down at its top-left — pick any signal to plot: RPM, ESC Power, TIT, EGT/Glow, Bearing, Coil, DC Voltage, DC Current, ESC Temp, Battery, Current 34, Current 35, Fuel Flow, or Throttle. Defaults are RPM, ESC Power, TIT and Coil.

NOTE: A chart only draws a signal that has data. If a chart looks blank, the signal it is set to has no valid readings right now (e.g. RPM when the ESC is off, or a thermocouple that reads OPEN). Point it at a live signal.

## 3.2 Engine Data gauges (bottom-left)

A row of numeric gauges with warning colors: Shaft Speed (RPM), Turbine Inlet Temp, Glow Area Temp, Bearing Temp, Coil Temp, DC Voltage, DC Current, DC Power, Battery %, ESC Temp, Fuel Flow (ml/min), and the two hall Current sensors (34 & 35). A temperature gauge turns amber near its limit and red at/over it. A thermocouple with no probe shows OPEN in red.

The two current gauges also show the raw ADC voltage underneath (e.g. “A (1.505 V)”) to help diagnose the sensor.

## 3.3 ESC — Throttle / RPM Governor (middle)

■ ESC: ARMED / DISARMED button — the microDRIVE refuses to spin the motor unless the ECU broadcasts an arming signal. Click to arm (with a confirmation); the button turns red when armed. Arm before commanding throttle; disarm (or ABORT) to make it safe.
■ PID CONTROL button — toggles the RPM governor. Off = the big slider is manual throttle %. On = the slider is an RPM setpoint and the PID holds that RPM.
■ Kc / Ti / Td fields + Send gains — the governor PID gains (Ti and Td in minutes, matching the LabVIEW convention). Type new values and click Send gains.
■ SP / THR readouts — the current RPM setpoint and the throttle % the ECU is actually commanding. ■ Speed slider — the large vertical slider. It sets throttle % (governor off) or RPM setpoint (governor on). It auto-switches labels.
■ Ramp Up / Pause / Ramp Down + Ramp rate — ramps the throttle up or down at the configured %/s instead of jumping.
■ STOP MOTOR — cancels ramp and governor and sets throttle to 0 (stays armed).

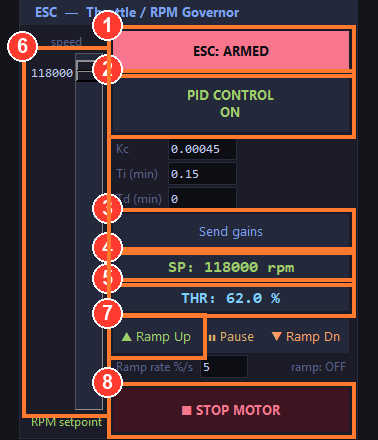
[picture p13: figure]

ESC / Throttle / RPM Governor panel.
1 ESC: ARMED / DISARMED — arm the ESC (red = armed). 2 PID CONTROL — toggle the RPM governor.
3 Send gains — push the Kc / Ti / Td fields above it.
4 SP — current RPM setpoint.
5 THR — throttle % the ECU is commanding.
6 Speed slider — throttle % (governor off) or RPM setpoint (governor on). 7 Ramp Up / Pause / Ramp Down — ramp the throttle at the set rate.
8 STOP MOTOR — throttle to 0 (stays armed).

## 3.4 Fuel — Pumps + Glow + Solenoids (middle)

■ Pump 1 / Pump 2 sliders — set each fuel pump's PWM duty 0–100%. Fuel flow is shown in ml/min via the pump calibration curve.

■ Pumps STOP — both pumps to zero.
■ FUEL SHUT OFF — a latch that forces both pumps to 0 and blocks them until released. Turns dark red when engaged.
■ Glow plug ON / OFF with a status lamp.
■ Solenoid 1 / Solenoid 2 ON / OFF with lamps. “On” drives the MOSFET at the Solenoid-ON-duty parameter (default 50% ≈ 6 V on a 12 V bus).

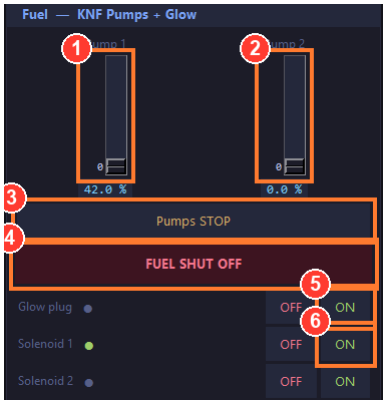
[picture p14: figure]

Fuel panel: pumps, glow plug, solenoids.
1 Pump 1 slider — fuel pump 1 duty (flow shown in ml/min). 2 Pump 2 slider — fuel pump 2 duty.
3 Pumps STOP — both pumps to zero.
4 FUEL SHUT OFF — latch that forces both pumps to 0.
5 Glow plug ON / OFF — with status lamp.
6 Solenoid 1 / 2 ON / OFF — drives the coil at ~6 V.

## 3.5 Current Sensor Cal (middle)

Live raw voltage for GPIO34 and GPIO35, plus calibration controls: a Zero V and A/V field with Apply; Zero now (@0A) which captures the present voltage as the zero point; preset buttons Uni 100A/5V and Bipolar ±100A/5V; and a Turns field for the multi-turn trick (pass the wire through the sensor N times to multiply a small current, then click Apply N turns).

## 3.6 Engine Sequencer (right)

■ AUTO START — runs the full automatic start sequence (with a confirmation dialog). See Section 4. ■ STOP (cooldown) — normal shutdown: cuts fuel and glow, then motors the engine to cool it before stopping.
■ MANUAL MODE — puts the ECU in manual so you can drive pumps, glow, solenoids and throttle directly. Failsafes stay active.
■ RESET FAULT — clears a latched FAULT once the cause is resolved.

■ Sequence progress strip — highlights the current step (PRECHECK → GLOW → SPOOL → IGNITION → WARMUP → RUNNING).

## 3.7 Parameters panel (right)

A scrolling list of every engine parameter with an editable field. Buttons:

■ Apply all (live) — send all fields to the ECU's live RAM (takes effect immediately, lost on reboot). ■ Save to ECU — apply, then persist to the ECU's flash so the values survive a power cycle.
■ Read from ECU — pull the ECU's current values back into the fields.
■ Save local — save the fields to a JSON file on the PC.

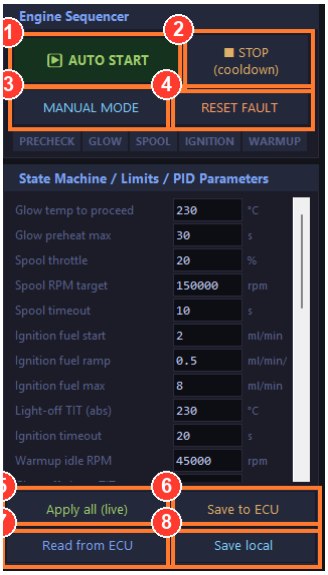
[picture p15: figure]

Engine Sequencer (top) and the Parameters panel with its four buttons.
1 AUTO START — run the automatic start sequence.
2 STOP (cooldown) — normal shutdown with cooldown motoring. 3 MANUAL MODE — direct control of each actuator.
4 RESET FAULT — clear a latched fault.
5 Apply all (live) — send fields to ECU RAM.
6 Save to ECU — persist parameters to ECU flash.

7 Read from ECU — pull the ECU's values into the fields.
8 Save local — save fields to a PC file.

NOTE: Two separate memories: Save to ECU stores engine parameters in the ECU's flash; the ESC Parameters panel's Save NVM stores ESC settings in the ESC's own flash. They are independent.

## 3.8 ESC Parameters panel (right)

Reads and writes the microDRIVE's own DroneCAN settings. Type a case-sensitive name (e.g. PH_CUR_LIM) and a value. Buttons: Get, Set, List all (dumps all ~99 ESC parameters to the log), Save NVM (persist to the ESC — the ESC reboots itself afterward), and Restart ESC (reboot / clear latched ESC errors).

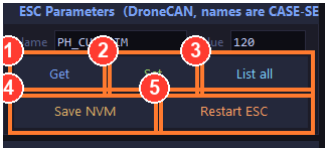
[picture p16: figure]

ESC Parameters panel (DroneCAN). Type a case-sensitive name and value. 1 Get — read the named parameter from the ESC.
2 Set — write the value to the ESC (live).
3 List all — dump every ESC parameter to the log.
4 Save NVM — persist ESC settings (ESC reboots).
5 Restart ESC — reboot the ESC / clear latched errors.

## 3.9 Events / Terminal (right)

A scrolling log of ECU events (state changes, faults, parameter echoes) and a text box at the bottom where you can type any serial command directly (Section 7). A mid-run “ESP32 REBOOTED” line here (red if a brownout) means the board lost power and reset.

# 4. The Automatic Start Sequence

Pressing AUTO START (or eng start) runs a state machine. Each step's thresholds and timeouts are parameters you can tune (Section 5). The sequence:

State | What happens | Advances when | Fails if
PRECHECK | Verifies fuel isn't shut off, TIT thermocouple is valid, ESC telemetry is present; arms the ESC and turns the glow plug on. | Checks pass | Any check fails
GLOW | Preheats the glow plug. | Glow-area temp reaches “Glow temp to proceed”, or the preheat time elapses | —
SPOOL | Motors the turbine on the ESC at “Spool throttle”. | RPM reaches “Spool RPM target” | RPM not reached before “Spool timeout” (SPOOL_FAIL)
IGNITION | Introduces fuel on pump 1, ramping it up in ml/min. | TIT reaches “Light-off TIT” (combustion detected) | No light-off before “Ignition timeout” (IGN_TIMEOUT)
WARMUP | Governor holds “Warmup idle RPM”; glow plug turns off once TIT passes “Glow off above TIT”. | RPM is within 10% of warmup idle | —
RUNNING | Engine at idle under governor / operator control. | Operator commands | Any failsafe
COOLDOW N | On STOP: fuel and glow off, motors the engine to cool. | TIT drops below “Cooldown until TIT”, or cooldown time elapses | —

CAUTION: The start parameters shipped are conservative starting points. Verify each against your engine on the bench before a real light-up — especially spool throttle vs. spool RPM target, and the ignition fuel values against what your pump can actually deliver.

## 4.1 Manual mode

MANUAL MODE lets you exercise each actuator independently: pump sliders, glow, solenoids, and either manual throttle or the governor. The failsafe supervisor still runs, so an over-temp or ESC-loss will still trip a FAULT and make everything safe.

# 5. Failsafes

Whenever anything is live (a sequence is running, or an output is on, or in manual mode), the ECU checks these every 50 ms. Any trip immediately makes everything safe (fuel, glow, throttle to zero; ESC disarmed) and latches a FAULT that names the cause. Clear it with RESET FAULT after fixing the problem. All thresholds are editable parameters.

Fault | Trips when
TIT_OVER | Turbine inlet temp reaches TIT max
COIL_OVER | Generator coil temp reaches Coil max
BEARING_OVER | Bearing temp reaches Bearing max
OVERSPEED | RPM reaches Max RPM
FLAMEOUT | Engine is lit and fuel is on but TIT falls below the Flameout TIT floor
ESC_LOSS | ESC telemetry is older than the ESC-loss timeout while throttle is commanded
TC_LOSS | TIT thermocouple goes invalid during a running sequence
IGN_TIMEOUT | No light-off within the ignition timeout
SPOOL_FAIL | Spool RPM not reached within the spool timeout
PRECHECK_FAIL | A precheck condition (fuel shutoff / TIT / ESC) not met at start
ABORT | Operator pressed ABORT ALL / eng abort

# 6. Parameter Reference

Every parameter is editable in the Parameters panel or with eng set <name> <value>. Save to ECU persists them to flash.

Name | Label | Unit | Meaning
glow_temp | Glow temp to proceed | °C | Glow-area temp that ends preheat and starts spool
glow_time | Glow preheat max | s | Max preheat time before proceeding anyway
spool_duty | Spool throttle | % | ESC throttle used to motor the turbine during spool
spool_rpm | Spool RPM target | rpm | RPM to reach before fuel is introduced
spool_time | Spool timeout | s | Fail to SPOOL_FAIL if not reached
ign_pump | Ignition fuel start | ml/min | Pump 1 fuel flow when fuel is first introduced
ign_ramp | Ignition fuel ramp | ml/min/s | Rate the ignition fuel is increased
ign_pump_max | Ignition fuel max | ml/min | Ceiling on ignition fuel (anti-flood)
lightoff_tit | Light-off TIT (abs) | °C | Absolute TIT that declares combustion / light-off
ign_timeout | Ignition timeout | s | Fail to IGN_TIMEOUT if no light-off
warmup_rpm | Warmup idle RPM | rpm | Governor target after light-off
glow_off_tit | Glow off above TIT | °C | TIT at which the glow plug switches off
tit_max | TIT max (fault) | °C | Over-temp failsafe on turbine inlet temp
coil_max | Coil max (fault) | °C | Over-temp failsafe on generator coil
bearing_max | Bearing max (fault) | °C | Over-temp failsafe on bearing
max_rpm | Max RPM (fault) | rpm | Overspeed failsafe + ramp/governor ceiling
flameout_tit | Flameout TIT floor | °C | Lit + fuel-on + TIT below this = flameout
esc_loss | ESC loss timeout | s | ESC telemetry age that triggers ESC_LOSS
cool_duty | Cooldown throttle | % | Motoring throttle during cooldown
cool_tit | Cooldown until TIT | °C | Cooldown ends below this temp
cool_time | Cooldown max time | s | Max cooldown duration
fuel_density | Fuel density | g/ml | Used for the g/s fuel estimate (kerosene ~0.84)
gov_kc | PID Kc | %/rpm | Governor proportional gain
gov_ti | PID Ti | min | Governor integral time (minutes)
gov_td | PID Td | min | Governor derivative time (minutes)
gov_min | PID output min | % | Lower throttle clamp for the governor (LabVIEW 15%)
gov_max | PID output max | % | Upper throttle clamp for the governor
gov_slew | Throttle slew limit | %/s | Max rate the throttle output can change
ramp_rate | Ramp rate | %/s | Manual ramp up/down rate
batt_min | Battery 0% voltage | V | Voltage mapped to 0% battery
batt_max | Battery 100% voltage | V | Voltage mapped to 100% battery
sol_duty | Solenoid ON duty | % | PWM duty for solenoid “on” (50% ≈ 6 V of 12 V)

# 7. Serial Command Reference

Anything the buttons do can also be typed in the Events / Terminal box. Commands are case-insensitive except ESC parameter names and serial2 send text.

## 7.1 Engine control

Command | Action
eng start | Begin the automatic start sequence
eng stop | Normal shutdown into COOLDOWN
eng abort | Emergency stop, latch FAULT
eng reset | Clear a latched fault
eng manual | Enter manual mode
eng status | Print full engine status
eng params | List all parameters
eng set <name> <value> | Edit a parameter (live RAM)
eng save | Persist parameters to ECU flash
eng defaults | Clear saved params (code defaults on next boot)
gov on | off | Enable / disable the RPM governor
gov sp <rpm> | Set the governor RPM setpoint
gov gains <kc> <ti> <td> | Set PID gains (Ti/Td in minutes)
thr <0-100> | Manual throttle percent (governor off)
ramp up | down | pause | off | Throttle ramp control
ramp rate <pct/s> | Set the ramp rate
pump <1|2> <0-100> | Set a fuel pump duty
pump stop | Stop both pumps
glow on | off | Glow plug on/off
sol <1|2> on | off | Solenoid on (drives sol_duty %) / off
fuel cut on | off | Engage / release the fuel-shutoff latch

## 7.2 ESC / CAN (DroneCAN)

Command | Action
can | CAN status + decoded ESC telemetry
can esc | Show ESC telemetry
can arm | disarm | Broadcast armed / disarmed to the ESC
can duty <-100..100> | Duty-cycle command (RawCommand)
can rpm <setpoint> | Closed-loop RPM command (RPMCommand)
can brake <0-100> | Regenerative brake (needs Reversible mode)

Command | Action
can stop | Zero the ESC command
can param list | List all ESC parameters
can param get <NAME> | Read an ESC parameter (case-sensitive)
can param set <NAME> <v> | Write an ESC parameter
can save | Persist ESC params to ESC NVM (ESC reboots)
can restart | Reboot the ESC / clear latched errors
can baud <125|250|500|1000> | Change CAN bitrate (DroneCAN = 1000)
can print on | off | Toggle raw CAN frame printing

## 7.3 Sensors, stream & diagnostics

Command | Action
status | Full pin/sensor/health status dump
stream on | off | Enable / disable the live data stream
stream rate <1-50> | Set stream rate in Hz (TCs sample at 10 Hz)
tc read <1-4|all> | Read thermocouple(s)
tc scan | Probe all expander CS bits (diagnostic)
tc mode 31855 | 6675 | Select thermocouple chip type
current all | a | b | Read the hall current sensors
current cal <zeroV> <A_per_V> | Calibrate the current sensors
analog all | vp|vn|a|b | Read raw ADC inputs
i2c scan | Scan the I2C bus
i2c recover | Force I2C expander recovery
serial2 send <text> | Send text to the Pixhawk UART
serial2 baud <rate> | Set Serial2 baud (Pixhawk telem = 57600)
help | ? | Print the on-board command list

# 8. Subsystem Notes

## 8.1 Fuel system & pump calibration

The fuel pump is a positive-displacement gear pump (Hausl ZP25M14F). Its flow-vs-duty curve is nonlinear with a hard deadband: no flow below ~28% duty, then it jumps to ~57 ml/min at 29% and rises to ~210 ml/min at 50%. The ECU stores your measured calibration points and interpolates between them, so commands in ml/min map to the correct duty and the Fuel Flow gauge is accurate.

CAUTION: Because of the deadband, this pump cannot deliver a steady flow below ~57 ml/min. If your ignition fuel needs to be lower than that, the pump must be pulsed (a firmware feature that can be added) rather than run at a low continuous duty.

## 8.2 ESC (Hargrave microDRIVE LPi)

The ESC speaks DroneCAN at 1 Mbps. The ECU acts as the node-ID allocator, broadcasts its own node status and the arming signal, decodes the ESC's telemetry (RPM, voltage, current, temperature, error flags), and can command duty, RPM or brake. Key ESC settings you may need (via the ESC Parameters panel): PH_CUR_LIM (phase current, 120 A for the 1500 W engine), BUS_CUR_LIM, and MOT_POLE_PAIRS (must match your motor so reported RPM is mechanical, not electrical).

WARNING: The ESC will not spin unless it is armed and it has seen a zero throttle first. Arm with the ESC:ARMED button (or the sequencer arms it automatically). If the ESC blinks a warning/error, use Restart ESC to clear a latched fault.

## 8.3 Current sensors

Two QNDB6 hall sensors (100 A / 5 V) on GPIO34 and GPIO35. Because the ESP32 ADC only reads to 3.3 V, a 5 V-output sensor clips above ~66 A on a single pass. For small currents, use the multi-turn trick in the Current Sensor Cal panel. Verify direction: a unidirectional sensor reads 0 V for reverse current — if the raw voltage sits at 0 while current flows, reverse the wire through the sensor.

## 8.4 Thermocouples

Four MAX31855 K-type modules on a shared SPI bus, each selected through the PCF8575 I2C expander. TC1=TIT, TC2=EGT, TC3=Bearing, TC4=Coil. A channel with no probe (or an open probe) reads OPEN; the chip itself still reports a healthy cold-junction temperature. The firmware auto-recovers the I2C bus if electrical noise wedges the expander.

## 8.5 Solenoids & glow plug

The glow plug is a simple on/off MOSFET switch (M1). The two solenoids are driven with PWM at the sol_duty parameter (default 50%), which averages through the coil inductance to ~6 V on a 12 V bus — matching a 6 V-rated coil. Tune sol_duty to hit the exact coil voltage.

# 9. Troubleshooting

Symptom | Likely cause & fix
Heartbeat works but no live data | The stream is off. Type stream on, or reconnect (the GUI enables it automatically).
Everything goes dark at once (no temp, no ESC, weak solenoid) | The ESP32 reset / browned out. Look for a red “ESP32 REBOOTED — BROWNOUT” in the log. Fix power/grounding: keep ESC and high-current returns off the ESP32 signal ground; give the ESP32 a clean 5 V. A full power-cycle recovers it.
Thermocouples all read OPEN after having worked | Usually the probes; the chips are alive. If truly no SPI data, the I2C expander wedged — i2c recover, or power-cycle. Check status for expander OK and I2C fail count.
No ESC data; can status shows bus_err climbing fast | ESC not on the bus. Check ESC power, CANH/CANL wiring (not swapped), and 120 Ω termination at both ends.
ESC won't spin | Not armed, or a latched ESC error. Arm it; if it still refuses, Restart ESC. Confirm PH_CUR_LIM and MOT_POLE_PAIRS.
Current sensor reads 0 while current flows | Reverse current direction (unidirectional sensor) or Common not tied to ESP32 GND. Reverse the wire through the sensor / bond the grounds.
Current reading is flickery / too low | A few amps on a 100 A sensor sits in ADC noise. Use the multi-turn trick; the firmware already low-pass filters the channel.
COM port not found / changes number | The CH340 re-enumerates on replug. Pick whichever port appears; unplug and replug USB if none shows.

## 9.1 Safety checklist before a run

■ Know where ABORT ALL is; test that STOP MOTOR and fuel-shutoff respond.
■ Confirm all failsafe limits (TIT/coil/bearing/overspeed) match your engine and are saved to the ECU. ■ Verify the ESC arms and disarms, and that MOT_POLE_PAIRS is correct.
■ Check the fuel calibration and that ignition fuel is within what the pump can deliver.
■ Confirm clean, solid power to the ESP32 and proper grounding to avoid brownout resets.
■ Clear the area; treat every armed/fueled state as live.

This manual reflects the UMGT Engine firmware and dashboard as configured for the project. Parameter values and pump calibration are engine-specific — always verify against your hardware before operating.

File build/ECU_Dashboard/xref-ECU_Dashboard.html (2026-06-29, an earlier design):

# modulegraph cross reference for ecu_dashboard.py, pyi_rth__tkinter.py, pyi_rth_inspect.py

ecu_dashboard.py Script

imports: _collections_abc • _weakrefset • abc • codecs • collections • copyreg • encodings • encodings.aliases • encodings.ascii • encodings.base64_codec • encodings.big5 • encodings.big5hkscs • encodings.bz2_codec • encodings.charmap • encodings.cp037 • encodings.cp1006 • encodings.cp1026 • encodings.cp1125 • encodings.cp1140 • encodings.cp1250 • encodings.cp1251 • encodings.cp1252 • encodings.cp1253 • encodings.cp1254 • encodings.cp1255 • encodings.cp1256 • encodings.cp1257 • encodings.cp1258 • encodings.cp273 • encodings.cp424 • encodings.cp437 • encodings.cp500 • encodings.cp720 • encodings.cp737 • encodings.cp775 • encodings.cp850 • encodings.cp852 • encodings.cp855 • encodings.cp856 • encodings.cp857 • encodings.cp858 • encodings.cp860 • encodings.cp861 • encodings.cp862 • encodings.cp863 • encodings.cp864 • encodings.cp865 • encodings.cp866 • encodings.cp869 • encodings.cp874 • encodings.cp875 • encodings.cp932 • encodings.cp949 • encodings.cp950 • encodings.euc_jis_2004 • encodings.euc_jisx0213 • encodings.euc_jp • encodings.euc_kr • encodings.gb18030 • encodings.gb2312 • encodings.gbk • encodings.hex_codec • encodings.hp_roman8 • encodings.hz • encodings.idna • encodings.iso2022_jp • encodings.iso2022_jp_1 • encodings.iso2022_jp_2 • encodings.iso2022_jp_2004 • encodings.iso2022_jp_3 • encodings.iso2022_jp_ext • encodings.iso2022_kr • encodings.iso8859_1 • encodings.iso8859_10 • encodings.iso8859_11 • encodings.iso8859_13 • encodings.iso8859_14 • encodings.iso8859_15 • encodings.iso8859_16 • encodings.iso8859_2 • encodings.iso8859_3 • encodings.iso8859_4 • encodings.iso8859_5 • encodings.iso8859_6 • encodings.iso8859_7 • encodings.iso8859_8 • encodings.iso8859_9 • encodings.johab • encodings.koi8_r • encodings.koi8_t • encodings.koi8_u • encodings.kz1048 • encodings.latin_1 • encodings.mac_arabic • encodings.mac_croatian • encodings.mac_cyrillic • encodings.mac_farsi • encodings.mac_greek • encodings.mac_iceland • encodings.mac_latin2 • encodings.mac_roman • encodings.mac_romanian • encodings.mac_turkish • encodings.mbcs • encodings.oem • encodings.palmos • encodings.ptcp154 • encodings.punycode • encodings.quopri_codec • encodings.raw_unicode_escape • encodings.rot_13 • encodings.shift_jis • encodings.shift_jis_2004 • encodings.shift_jisx0213 • encodings.tis_620 • encodings.undefined • encodings.unicode_escape • encodings.utf_16 • encodings.utf_16_be • encodings.utf_16_le • encodings.utf_32 • encodings.utf_32_be • encodings.utf_32_le • encodings.utf_7 • encodings.utf_8 • encodings.utf_8_sig • encodings.uu_codec • encodings.zlib_codec • enum • functools • genericpath • heapq • io • keyword • linecache • locale • ntpath • operator • os • posixpath • pyi_rth__tkinter.py • pyi_rth_inspect.py • queue • re • re._casefix • re._compiler • re._constants • re._parser • reprlib • serial • serial.tools.list_ports • sre_compile • sre_constants • sre_parse • stat • threading • time • tkinter • tkinter.messagebox • tkinter.scrolledtext • tkinter.ttk • traceback • types • warnings • weakref

pyi_rth__tkinter.py Script

imports: os • sys

imported by: ecu_dashboard.py

pyi_rth_inspect.py Script

imports: inspect • os • sys • zipfile

imported by: ecu_dashboard.py

'System.IO' MissingModule

imported by: serial.serialcli

'collections.abc' MissingModule

imported by: importlib.resources.readers • inspect • logging • selectors • traceback • tracemalloc • typing

System MissingModule

imported by: serial.serialcli

__future__ SourceModule

imported by: _colorize • importlib.metadata • importlib.metadata._meta • importlib.resources.readers • serial • serial.serialcli • serial.serialjava • serial.serialposix • serial.serialutil • serial.serialwin32 • serial.tools.list_ports • serial.tools.list_ports_common • serial.tools.list_ports_linux • serial.tools.list_ports_osx • serial.tools.list_ports_posix • serial.tools.list_ports_windows • serial.win32

_abc (builtin module)

imported by: abc

_aix_support SourceModule

imports: contextlib • os • subprocess • sys • sysconfig

imported by: sysconfig

_ast (builtin module)

imported by: ast

_bisect (builtin module)

imported by: bisect

_blake2 (builtin module)

imported by: hashlib

_bz2 C:\Users\owen.maute\AppData\Local\Programs\Python\Python313\DLLs\_bz2.pyd

imported by: bz2

_codecs (builtin module)

imported by: codecs

_codecs_cn (builtin module)

imported by: encodings.gb18030 • encodings.gb2312 • encodings.gbk • encodings.hz

_codecs_hk (builtin module)

imported by: encodings.big5hkscs

_codecs_iso2022 (builtin module)

imported by: encodings.iso2022_jp • encodings.iso2022_jp_1 • encodings.iso2022_jp_2 • encodings.iso2022_jp_2004 • encodings.iso2022_jp_3 • encodings.iso2022_jp_ext • encodings.iso2022_kr

_codecs_jp (builtin module)

imported by: encodings.cp932 • encodings.euc_jis_2004 • encodings.euc_jisx0213 • encodings.euc_jp • encodings.shift_jis • encodings.shift_jis_2004 • encodings.shift_jisx0213

_codecs_kr (builtin module)

imported by: encodings.cp949 • encodings.euc_kr • encodings.johab

_codecs_tw (builtin module)

imported by: encodings.big5 • encodings.cp950

_collections (builtin module)

imported by: collections • threading

_collections_abc SourceModule

imports: abc • sys • warnings

imported by: collections • contextlib • ecu_dashboard.py • locale • os • pathlib._local • random • types • weakref

_colorize SourceModule

imports: __future__ • nt • os • sys • typing

imported by: traceback

_compat_pickle SourceModule

imported by: _pickle • pickle

_compression SourceModule

imports: io • sys

imported by: bz2 • gzip • lzma

_contextvars (builtin module)

imported by: contextvars

_csv (builtin module)

imported by: csv

_ctypes C:\Users\owen.maute\AppData\Local\Programs\Python\Python313\DLLs\_ctypes.pyd

imported by: ctypes

_datetime (builtin module)

imports: _strptime • time

imported by: datetime

_decimal C:\Users\owen.maute\AppData\Local\Programs\Python\Python313\DLLs\_decimal.pyd

imported by: decimal

_frozen_importlib ExcludedModule

imported by: importlib • importlib.abc

_frozen_importlib_external MissingModule

imported by: importlib • importlib._bootstrap • importlib.abc

_functools (builtin module)

imported by: functools

_hashlib C:\Users\owen.maute\AppData\Local\Programs\Python\Python313\DLLs\_hashlib.pyd

imported by: hashlib

_heapq (builtin module)

imported by: heapq

_imp (builtin module)

imported by: importlib • importlib._bootstrap_external • importlib.util

_io (builtin module)

imported by: importlib._bootstrap_external • io

_json (builtin module)

imports: json.decoder

imported by: json.decoder • json.encoder • json.scanner

_locale (builtin module)

imported by: locale

_lzma C:\Users\owen.maute\AppData\Local\Programs\Python\Python313\DLLs\_lzma.pyd

imported by: lzma

_md5 (builtin module)

imported by: hashlib

_multibytecodec (builtin module)

imported by: encodings.big5 • encodings.big5hkscs • encodings.cp932 • encodings.cp949 • encodings.cp950 • encodings.euc_jis_2004 • encodings.euc_jisx0213 • encodings.euc_jp • encodings.euc_kr • encodings.gb18030 • encodings.gb2312 • encodings.gbk • encodings.hz • encodings.iso2022_jp • encodings.iso2022_jp_1 • encodings.iso2022_jp_2 • encodings.iso2022_jp_2004 • encodings.iso2022_jp_3 • encodings.iso2022_jp_ext • encodings.iso2022_kr • encodings.johab • encodings.shift_jis • encodings.shift_jis_2004 • encodings.shift_jisx0213

_opcode (builtin module)

imported by: dis • opcode

_opcode_metadata SourceModule

imported by: opcode

_operator (builtin module)

imported by: operator

_pickle (builtin module)

imports: _compat_pickle • codecs • copyreg

imported by: pickle

_posixsubprocess MissingModule

imports: gc

imported by: subprocess

_py_abc SourceModule

imports: _weakrefset

imported by: abc

_pydatetime SourceModule

imports: _strptime • math • operator • sys • time • warnings

imported by: datetime

_pydecimal SourceModule

imports: collections • contextvars • itertools • locale • math • numbers • re • sys

imported by: decimal

_queue C:\Users\owen.maute\AppData\Local\Programs\Python\Python313\DLLs\_queue.pyd

imported by: queue

_random (builtin module)

imported by: random

_sha1 (builtin module)

imported by: hashlib

_sha2 (builtin module)

imported by: hashlib • random

_sha3 (builtin module)

imported by: hashlib

_signal (builtin module)

imported by: signal

_socket C:\Users\owen.maute\AppData\Local\Programs\Python\Python313\DLLs\_socket.pyd

imported by: socket • types

_sre (builtin module)

imports: copy • re

imported by: re • re._compiler • re._constants

_stat (builtin module)

imported by: stat

_statistics (builtin module)

imported by: statistics

_string (builtin module)

imported by: string

_strptime SourceModule

imports: _thread • calendar • datetime • locale • os • re • time • warnings

imported by: _datetime • _pydatetime • time

_struct (builtin module)

imported by: struct

_suggestions (builtin module)

imported by: traceback

_sysconfig (builtin module)

imported by: sysconfig

_thread (builtin module)

imported by: _strptime • functools • reprlib • tempfile • threading

_threading_local SourceModule

imports: contextlib • threading • weakref

imported by: threading

_tkinter C:\Users\owen.maute\AppData\Local\Programs\Python\Python313\DLLs\_tkinter.pyd

imported by: tkinter

_tokenize (builtin module)

imported by: tokenize

_tracemalloc (builtin module)

imported by: tracemalloc

_typing (builtin module)

imported by: typing

_warnings (builtin module)

imported by: importlib._bootstrap_external • warnings

_weakref (builtin module)

imported by: _weakrefset • collections • weakref

_weakrefset SourceModule

imports: _weakref • types

imported by: _py_abc • ecu_dashboard.py • threading • weakref

_winapi (builtin module)

imported by: encodings • ntpath • shutil • subprocess • sysconfig

abc SourceModule

imports: _abc • _py_abc

imported by: _collections_abc • contextlib • dataclasses • ecu_dashboard.py • email._policybase • functools • importlib._abc • importlib.abc • importlib.metadata • importlib.resources.abc • inspect • io • numbers • os • selectors • typing

argparse SourceModule

imports: copy • gettext • os • re • shutil • sys • textwrap • warnings

imported by: ast • calendar • dis • gzip • inspect • py_compile • random • serial.tools.list_ports • tarfile • tokenize • zipfile

array (builtin module)

imported by: serial.serialposix • serial.serialutil • socket

ast SourceModule

imports: _ast • argparse • collections • contextlib • enum • inspect • re • sys • warnings

imported by: inspect • traceback

atexit (builtin module)

imported by: logging • weakref

base64 SourceModule

imports: binascii • getopt • io • re • struct • sys

imported by: email._encoded_words • email.base64mime • email.encoders • encodings.base64_codec

binascii (builtin module)

imported by: base64 • email._encoded_words • email.base64mime • email.contentmanager • email.header • email.message • encodings.hex_codec • encodings.uu_codec • quopri • zipfile

bisect SourceModule

imports: _bisect

imported by: random • statistics

builtins (builtin module)

imported by: bz2 • codecs • enum • gettext • gzip • inspect • locale • lzma • operator • reprlib • subprocess • tarfile • tokenize • warnings

bz2 SourceModule

imports: _bz2 • _compression • builtins • io • os

imported by: encodings.bz2_codec • shutil • tarfile • zipfile

calendar SourceModule

imports: argparse • datetime • enum • itertools • locale • sys • warnings

imported by: _strptime • email._parseaddr

codecs SourceModule

imports: _codecs • builtins • encodings • sys

imported by: _pickle • ecu_dashboard.py • encodings • encodings.ascii • encodings.base64_codec • encodings.big5 • encodings.big5hkscs • encodings.bz2_codec • encodings.charmap • encodings.cp037 • encodings.cp1006 • encodings.cp1026 • encodings.cp1125 • encodings.cp1140 • encodings.cp1250 • encodings.cp1251 • encodings.cp1252 • encodings.cp1253 • encodings.cp1254 • encodings.cp1255 • encodings.cp1256 • encodings.cp1257 • encodings.cp1258 • encodings.cp273 • encodings.cp424 • encodings.cp437 • encodings.cp500 • encodings.cp720 • encodings.cp737 • encodings.cp775 • encodings.cp850 • encodings.cp852 • encodings.cp855 • encodings.cp856 • encodings.cp857 • encodings.cp858 • encodings.cp860 • encodings.cp861 • encodings.cp862 • encodings.cp863 • encodings.cp864 • encodings.cp865 • encodings.cp866 • encodings.cp869 • encodings.cp874 • encodings.cp875 • encodings.cp932 • encodings.cp949 • encodings.cp950 • encodings.euc_jis_2004 • encodings.euc_jisx0213 • encodings.euc_jp • encodings.euc_kr • encodings.gb18030 • encodings.gb2312 • encodings.gbk • encodings.hex_codec • encodings.hp_roman8 • encodings.hz • encodings.idna • encodings.iso2022_jp • encodings.iso2022_jp_1 • encodings.iso2022_jp_2 • encodings.iso2022_jp_2004 • encodings.iso2022_jp_3 • encodings.iso2022_jp_ext • encodings.iso2022_kr • encodings.iso8859_1 • encodings.iso8859_10 • encodings.iso8859_11 • encodings.iso8859_13 • encodings.iso8859_14 • encodings.iso8859_15 • encodings.iso8859_16 • encodings.iso8859_2 • encodings.iso8859_3 • encodings.iso8859_4 • encodings.iso8859_5 • encodings.iso8859_6 • encodings.iso8859_7 • encodings.iso8859_8 • encodings.iso8859_9 • encodings.johab • encodings.koi8_r • encodings.koi8_t • encodings.koi8_u • encodings.kz1048 • encodings.latin_1 • encodings.mac_arabic • encodings.mac_croatian • encodings.mac_cyrillic • encodings.mac_farsi • encodings.mac_greek • encodings.mac_iceland • encodings.mac_latin2 • encodings.mac_roman • encodings.mac_romanian • encodings.mac_turkish • encodings.mbcs • encodings.oem • encodings.palmos • encodings.ptcp154 • encodings.punycode • encodings.quopri_codec • encodings.raw_unicode_escape • encodings.rot_13 • encodings.shift_jis • encodings.shift_jis_2004 • encodings.shift_jisx0213 • encodings.tis_620 • encodings.undefined • encodings.unicode_escape • encodings.utf_16 • encodings.utf_16_be • encodings.utf_16_le • encodings.utf_32 • encodings.utf_32_be • encodings.utf_32_le • encodings.utf_7 • encodings.utf_8 • encodings.utf_8_sig • encodings.uu_codec • encodings.zlib_codec • json • pickle • tokenize

collections Package

imports: _collections • _collections_abc • _weakref • copy • heapq • itertools • keyword • operator • reprlib • sys

imported by: _pydecimal • ast • contextlib • dis • ecu_dashboard.py • email.feedparser • functools • importlib.metadata • importlib.metadata._collections • importlib.resources.readers • inspect • pprint • queue • selectors • shutil • statistics • string • threading • tkinter • tokenize • typing • urllib.parse

contextlib SourceModule

imports: _collections_abc • abc • collections • functools • os • sys • types

imported by: _aix_support • _threading_local • ast • glob • importlib.metadata • importlib.resources._adapters • importlib.resources._common • importlib.resources.readers • subprocess • traceback • typing • zipfile._path

contextvars SourceModule

imports: _contextvars

imported by: _pydecimal

copy SourceModule

imports: copyreg • types • weakref

imported by: _sre • argparse • collections • dataclasses • email.generator • gettext • tarfile • weakref

copyreg SourceModule

imports: functools • operator

imported by: _pickle • copy • ecu_dashboard.py • pickle • re • typing

csv SourceModule

imports: _csv • io • re • types

imported by: importlib.metadata

ctypes Package

imports: _ctypes • ctypes._endian • nt • os • struct • sys • sysconfig • types • warnings

imported by: ctypes._endian • ctypes.wintypes • serial.serialwin32 • serial.tools.list_ports_osx • serial.tools.list_ports_windows • serial.win32

ctypes._endian SourceModule

imports: ctypes • sys

imported by: ctypes

ctypes.wintypes SourceModule

imports: ctypes

imported by: serial.tools.list_ports_windows • serial.win32

dataclasses SourceModule

imports: abc • copy • inspect • itertools • keyword • re • reprlib • sys • types

imported by: pprint

datetime SourceModule

imports: _datetime • _pydatetime • time

imported by: _strptime • calendar • email.utils

decimal SourceModule

imports: _decimal • _pydecimal • sys

imported by: fractions • statistics

dis SourceModule

imports: _opcode • argparse • collections • io • opcode • sys • types

imported by: inspect

email Package

imports: email._header_value_parser • email.charset • email.errors • email.header • email.parser

imported by: email._encoded_words • email._header_value_parser • email._parseaddr • email._policybase • email.base64mime • email.charset • email.contentmanager • email.encoders • email.errors • email.feedparser • email.generator • email.header • email.headerregistry • email.iterators • email.message • email.parser • email.policy • email.quoprimime • email.utils • importlib.metadata

email._encoded_words SourceModule

imports: base64 • binascii • email • email.errors • functools • re • string

imported by: email._header_value_parser • email.message

email._header_value_parser SourceModule

imports: email • email._encoded_words • email.errors • email.utils • operator • re • string • sys • urllib

imported by: email • email.headerregistry

email._parseaddr SourceModule

imports: calendar • email • time

imported by: email.utils

email._policybase SourceModule

imports: abc • email • email.charset • email.header • email.utils

imported by: email.feedparser • email.message • email.parser • email.policy

email.base64mime SourceModule

imports: base64 • binascii • email

imported by: email.charset • email.header

email.charset SourceModule

imports: email • email.base64mime • email.encoders • email.errors • email.quoprimime • functools

imported by: email • email._policybase • email.contentmanager • email.header • email.message • email.utils

email.contentmanager SourceModule

imports: binascii • email • email.charset • email.errors • email.message • email.quoprimime • sys

imported by: email.policy

email.encoders SourceModule

imports: base64 • email • quopri

imported by: email.charset

email.errors SourceModule

imports: email

imported by: email • email._encoded_words • email._header_value_parser • email.charset • email.contentmanager • email.feedparser • email.generator • email.header • email.headerregistry • email.message

email.feedparser SourceModule

imports: collections • email • email._policybase • email.errors • email.message • io • re

imported by: email.parser

email.generator SourceModule

imports: copy • email • email.errors • email.utils • io • random • re • sys • time

imported by: email.message

email.header SourceModule

imports: binascii • email • email.base64mime • email.charset • email.errors • email.quoprimime • re

imported by: email • email._policybase

email.headerregistry SourceModule

imports: email • email._header_value_parser • email.errors • email.utils • types

imported by: email.policy

email.iterators SourceModule

imports: email • io • sys

imported by: email.message

email.message SourceModule

imports: binascii • email • email._encoded_words • email._policybase • email.charset • email.errors • email.generator • email.iterators • email.policy • email.utils • io • quopri • re

imported by: email.contentmanager • email.feedparser • email.policy • importlib.metadata._adapters

email.parser SourceModule

imports: email • email._policybase • email.feedparser • io

imported by: email

email.policy SourceModule

imports: email • email._policybase • email.contentmanager • email.headerregistry • email.message • email.utils • re • sys

imported by: email.message

email.quoprimime SourceModule

imports: email • re • string

imported by: email.charset • email.contentmanager • email.header

email.utils SourceModule

imports: datetime • email • email._parseaddr • email.charset • os • random • re • socket • time • urllib.parse • warnings

imported by: email._header_value_parser • email._policybase • email.generator • email.headerregistry • email.message • email.policy

encodings Package

imports: _winapi • codecs • encodings • encodings.aliases • encodings.ascii • encodings.base64_codec • encodings.big5 • encodings.big5hkscs • encodings.bz2_codec • encodings.charmap • encodings.cp037 • encodings.cp1006 • encodings.cp1026 • encodings.cp1125 • encodings.cp1140 • encodings.cp1250 • encodings.cp1251 • encodings.cp1252 • encodings.cp1253 • encodings.cp1254 • encodings.cp1255 • encodings.cp1256 • encodings.cp1257 • encodings.cp1258 • encodings.cp273 • encodings.cp424 • encodings.cp437 • encodings.cp500 • encodings.cp720 • encodings.cp737 • encodings.cp775 • encodings.cp850 • encodings.cp852 • encodings.cp855 • encodings.cp856 • encodings.cp857 • encodings.cp858 • encodings.cp860 • encodings.cp861 • encodings.cp862 • encodings.cp863 • encodings.cp864 • encodings.cp865 • encodings.cp866 • encodings.cp869 • encodings.cp874 • encodings.cp875 • encodings.cp932 • encodings.cp949 • encodings.cp950 • encodings.euc_jis_2004 • encodings.euc_jisx0213 • encodings.euc_jp • encodings.euc_kr • encodings.gb18030 • encodings.gb2312 • encodings.gbk • encodings.hex_codec • encodings.hp_roman8 • encodings.hz • encodings.idna • encodings.iso2022_jp • encodings.iso2022_jp_1 • encodings.iso2022_jp_2 • encodings.iso2022_jp_2004 • encodings.iso2022_jp_3 • encodings.iso2022_jp_ext • encodings.iso2022_kr • encodings.iso8859_1 • encodings.iso8859_10 • encodings.iso8859_11 • encodings.iso8859_13 • encodings.iso8859_14 • encodings.iso8859_15 • encodings.iso8859_16 • encodings.iso8859_2 • encodings.iso8859_3 • encodings.iso8859_4 • encodings.iso8859_5 • encodings.iso8859_6 • encodings.iso8859_7 • encodings.iso8859_8 • encodings.iso8859_9 • encodings.johab • encodings.koi8_r • encodings.koi8_t • encodings.koi8_u • encodings.kz1048 • encodings.latin_1 • encodings.mac_arabic • encodings.mac_croatian • encodings.mac_cyrillic • encodings.mac_farsi • encodings.mac_greek • encodings.mac_iceland • encodings.mac_latin2 • encodings.mac_roman • encodings.mac_romanian • encodings.mac_turkish • encodings.mbcs • encodings.oem • encodings.palmos • encodings.ptcp154 • encodings.punycode • encodings.quopri_codec • encodings.raw_unicode_escape • encodings.rot_13 • encodings.shift_jis • encodings.shift_jis_2004 • encodings.shift_jisx0213 • encodings.tis_620 • encodings.undefined • encodings.unicode_escape • encodings.utf_16 • encodings.utf_16_be • encodings.utf_16_le • encodings.utf_32 • encodings.utf_32_be • encodings.utf_32_le • encodings.utf_7 • encodings.utf_8 • encodings.utf_8_sig • encodings.uu_codec • encodings.zlib_codec • sys

imported by: codecs • ecu_dashboard.py • encodings • encodings.aliases • encodings.ascii • encodings.base64_codec • encodings.big5 • encodings.big5hkscs • encodings.bz2_codec • encodings.charmap • encodings.cp037 • encodings.cp1006 • encodings.cp1026 • encodings.cp1125 • encodings.cp1140 • encodings.cp1250 • encodings.cp1251 • encodings.cp1252 • encodings.cp1253 • encodings.cp1254 • encodings.cp1255 • encodings.cp1256 • encodings.cp1257 • encodings.cp1258 • encodings.cp273 • encodings.cp424 • encodings.cp437 • encodings.cp500 • encodings.cp720 • encodings.cp737 • encodings.cp775 • encodings.cp850 • encodings.cp852 • encodings.cp855 • encodings.cp856 • encodings.cp857 • encodings.cp858 • encodings.cp860 • encodings.cp861 • encodings.cp862 • encodings.cp863 • encodings.cp864 • encodings.cp865 • encodings.cp866 • encodings.cp869 • encodings.cp874 • encodings.cp875 • encodings.cp932 • encodings.cp949 • encodings.cp950 • encodings.euc_jis_2004 • encodings.euc_jisx0213 • encodings.euc_jp • encodings.euc_kr • encodings.gb18030 • encodings.gb2312 • encodings.gbk • encodings.hex_codec • encodings.hp_roman8 • encodings.hz • encodings.idna • encodings.iso2022_jp • encodings.iso2022_jp_1 • encodings.iso2022_jp_2 • encodings.iso2022_jp_2004 • encodings.iso2022_jp_3 • encodings.iso2022_jp_ext • encodings.iso2022_kr • encodings.iso8859_1 • encodings.iso8859_10 • encodings.iso8859_11 • encodings.iso8859_13 • encodings.iso8859_14 • encodings.iso8859_15 • encodings.iso8859_16 • encodings.iso8859_2 • encodings.iso8859_3 • encodings.iso8859_4 • encodings.iso8859_5 • encodings.iso8859_6 • encodings.iso8859_7 • encodings.iso8859_8 • encodings.iso8859_9 • encodings.johab • encodings.koi8_r • encodings.koi8_t • encodings.koi8_u • encodings.kz1048 • encodings.latin_1 • encodings.mac_arabic • encodings.mac_croatian • encodings.mac_cyrillic • encodings.mac_farsi • encodings.mac_greek • encodings.mac_iceland • encodings.mac_latin2 • encodings.mac_roman • encodings.mac_romanian • encodings.mac_turkish • encodings.mbcs • encodings.oem • encodings.palmos • encodings.ptcp154 • encodings.punycode • encodings.quopri_codec • encodings.raw_unicode_escape • encodings.rot_13 • encodings.shift_jis • encodings.shift_jis_2004 • encodings.shift_jisx0213 • encodings.tis_620 • encodings.undefined • encodings.unicode_escape • encodings.utf_16 • encodings.utf_16_be • encodings.utf_16_le • encodings.utf_32 • encodings.utf_32_be • encodings.utf_32_le • encodings.utf_7 • encodings.utf_8 • encodings.utf_8_sig • encodings.uu_codec • encodings.zlib_codec • locale

encodings.aliases SourceModule

imports: encodings

imported by: ecu_dashboard.py • encodings • locale

encodings.ascii SourceModule

imports: codecs • encodings

imported by: ecu_dashboard.py • encodings

encodings.base64_codec SourceModule

imports: base64 • codecs • encodings

imported by: ecu_dashboard.py • encodings

encodings.big5 SourceModule

imports: _codecs_tw • _multibytecodec • codecs • encodings

imported by: ecu_dashboard.py • encodings

encodings.big5hkscs SourceModule

imports: _codecs_hk • _multibytecodec • codecs • encodings

imported by: ecu_dashboard.py • encodings

encodings.bz2_codec SourceModule

imports: bz2 • codecs • encodings

imported by: ecu_dashboard.py • encodings

encodings.charmap SourceModule

imports: codecs • encodings

imported by: ecu_dashboard.py • encodings

encodings.cp037 SourceModule

imports: codecs • encodings

imported by: ecu_dashboard.py • encodings

encodings.cp1006 SourceModule

imports: codecs • encodings

imported by: ecu_dashboard.py • encodings

encodings.cp1026 SourceModule

imports: codecs • encodings

imported by: ecu_dashboard.py • encodings

encodings.cp1125 SourceModule

imports: codecs • encodings

imported by: ecu_dashboard.py • encodings

encodings.cp1140 SourceModule

imports: codecs • encodings

imported by: ecu_dashboard.py • encodings

encodings.cp1250 SourceModule

imports: codecs • encodings

imported by: ecu_dashboard.py • encodings

encodings.cp1251 SourceModule

imports: codecs • encodings

imported by: ecu_dashboard.py • encodings

encodings.cp1252 SourceModule

imports: codecs • encodings

imported by: ecu_dashboard.py • encodings

encodings.cp1253 SourceModule

imports: codecs • encodings

imported by: ecu_dashboard.py • encodings

encodings.cp1254 SourceModule

imports: codecs • encodings

imported by: ecu_dashboard.py • encodings

encodings.cp1255 SourceModule

imports: codecs • encodings

imported by: ecu_dashboard.py • encodings

encodings.cp1256 SourceModule

imports: codecs • encodings

imported by: ecu_dashboard.py • encodings

encodings.cp1257 SourceModule

imports: codecs • encodings

imported by: ecu_dashboard.py • encodings

encodings.cp1258 SourceModule

imports: codecs • encodings

imported by: ecu_dashboard.py • encodings

encodings.cp273 SourceModule

imports: codecs • encodings

imported by: ecu_dashboard.py • encodings

encodings.cp424 SourceModule

imports: codecs • encodings

imported by: ecu_dashboard.py • encodings

encodings.cp437 SourceModule

imports: codecs • encodings

imported by: ecu_dashboard.py • encodings

encodings.cp500 SourceModule

imports: codecs • encodings

imported by: ecu_dashboard.py • encodings

encodings.cp720 SourceModule

imports: codecs • encodings

imported by: ecu_dashboard.py • encodings

encodings.cp737 SourceModule

imports: codecs • encodings

imported by: ecu_dashboard.py • encodings

encodings.cp775 SourceModule

imports: codecs • encodings

imported by: ecu_dashboard.py • encodings

encodings.cp850 SourceModule

imports: codecs • encodings

imported by: ecu_dashboard.py • encodings

encodings.cp852 SourceModule

imports: codecs • encodings

imported by: ecu_dashboard.py • encodings

encodings.cp855 SourceModule

imports: codecs • encodings

imported by: ecu_dashboard.py • encodings

encodings.cp856 SourceModule

imports: codecs • encodings

imported by: ecu_dashboard.py • encodings

encodings.cp857 SourceModule

imports: codecs • encodings

imported by: ecu_dashboard.py • encodings

encodings.cp858 SourceModule

imports: codecs • encodings

imported by: ecu_dashboard.py • encodings

encodings.cp860 SourceModule

imports: codecs • encodings

imported by: ecu_dashboard.py • encodings

encodings.cp861 SourceModule

imports: codecs • encodings

imported by: ecu_dashboard.py • encodings

encodings.cp862 SourceModule

imports: codecs • encodings

imported by: ecu_dashboard.py • encodings

encodings.cp863 SourceModule

imports: codecs • encodings

imported by: ecu_dashboard.py • encodings

encodings.cp864 SourceModule

imports: codecs • encodings

imported by: ecu_dashboard.py • encodings

encodings.cp865 SourceModule

imports: codecs • encodings

imported by: ecu_dashboard.py • encodings

encodings.cp866 SourceModule

imports: codecs • encodings

imported by: ecu_dashboard.py • encodings

encodings.cp869 SourceModule

imports: codecs • encodings

imported by: ecu_dashboard.py • encodings

encodings.cp874 SourceModule

imports: codecs • encodings

imported by: ecu_dashboard.py • encodings

encodings.cp875 SourceModule

imports: codecs • encodings

imported by: ecu_dashboard.py • encodings

encodings.cp932 SourceModule

imports: _codecs_jp • _multibytecodec • codecs • encodings

imported by: ecu_dashboard.py • encodings

encodings.cp949 SourceModule

imports: _codecs_kr • _multibytecodec • codecs • encodings

imported by: ecu_dashboard.py • encodings

encodings.cp950 SourceModule

imports: _codecs_tw • _multibytecodec • codecs • encodings

imported by: ecu_dashboard.py • encodings

encodings.euc_jis_2004 SourceModule

imports: _codecs_jp • _multibytecodec • codecs • encodings

imported by: ecu_dashboard.py • encodings

encodings.euc_jisx0213 SourceModule

imports: _codecs_jp • _multibytecodec • codecs • encodings

imported by: ecu_dashboard.py • encodings

encodings.euc_jp SourceModule

imports: _codecs_jp • _multibytecodec • codecs • encodings

imported by: ecu_dashboard.py • encodings

encodings.euc_kr SourceModule

imports: _codecs_kr • _multibytecodec • codecs • encodings

imported by: ecu_dashboard.py • encodings

encodings.gb18030 SourceModule

imports: _codecs_cn • _multibytecodec • codecs • encodings

imported by: ecu_dashboard.py • encodings

encodings.gb2312 SourceModule

imports: _codecs_cn • _multibytecodec • codecs • encodings

imported by: ecu_dashboard.py • encodings

encodings.gbk SourceModule

imports: _codecs_cn • _multibytecodec • codecs • encodings

imported by: ecu_dashboard.py • encodings

encodings.hex_codec SourceModule

imports: binascii • codecs • encodings

imported by: ecu_dashboard.py • encodings

encodings.hp_roman8 SourceModule

imports: codecs • encodings

imported by: ecu_dashboard.py • encodings

encodings.hz SourceModule

imports: _codecs_cn • _multibytecodec • codecs • encodings

imported by: ecu_dashboard.py • encodings

encodings.idna SourceModule

imports: codecs • encodings • re • stringprep • unicodedata

imported by: ecu_dashboard.py • encodings

encodings.iso2022_jp SourceModule

imports: _codecs_iso2022 • _multibytecodec • codecs • encodings

imported by: ecu_dashboard.py • encodings

encodings.iso2022_jp_1 SourceModule

imports: _codecs_iso2022 • _multibytecodec • codecs • encodings

imported by: ecu_dashboard.py • encodings

encodings.iso2022_jp_2 SourceModule

imports: _codecs_iso2022 • _multibytecodec • codecs • encodings

imported by: ecu_dashboard.py • encodings

encodings.iso2022_jp_2004 SourceModule

imports: _codecs_iso2022 • _multibytecodec • codecs • encodings

imported by: ecu_dashboard.py • encodings

encodings.iso2022_jp_3 SourceModule

imports: _codecs_iso2022 • _multibytecodec • codecs • encodings

imported by: ecu_dashboard.py • encodings

encodings.iso2022_jp_ext SourceModule

imports: _codecs_iso2022 • _multibytecodec • codecs • encodings

imported by: ecu_dashboard.py • encodings

encodings.iso2022_kr SourceModule

imports: _codecs_iso2022 • _multibytecodec • codecs • encodings

imported by: ecu_dashboard.py • encodings

encodings.iso8859_1 SourceModule

imports: codecs • encodings

imported by: ecu_dashboard.py • encodings

encodings.iso8859_10 SourceModule

imports: codecs • encodings

imported by: ecu_dashboard.py • encodings

encodings.iso8859_11 SourceModule

imports: codecs • encodings

imported by: ecu_dashboard.py • encodings

encodings.iso8859_13 SourceModule

imports: codecs • encodings

imported by: ecu_dashboard.py • encodings

encodings.iso8859_14 SourceModule

imports: codecs • encodings

imported by: ecu_dashboard.py • encodings

encodings.iso8859_15 SourceModule

imports: codecs • encodings

imported by: ecu_dashboard.py • encodings

encodings.iso8859_16 SourceModule

imports: codecs • encodings

imported by: ecu_dashboard.py • encodings

encodings.iso8859_2 SourceModule

imports: codecs • encodings

imported by: ecu_dashboard.py • encodings

encodings.iso8859_3 SourceModule

imports: codecs • encodings

imported by: ecu_dashboard.py • encodings

encodings.iso8859_4 SourceModule

imports: codecs • encodings

imported by: ecu_dashboard.py • encodings

encodings.iso8859_5 SourceModule

imports: codecs • encodings

imported by: ecu_dashboard.py • encodings

encodings.iso8859_6 SourceModule

imports: codecs • encodings

imported by: ecu_dashboard.py • encodings

encodings.iso8859_7 SourceModule

imports: codecs • encodings

imported by: ecu_dashboard.py • encodings

encodings.iso8859_8 SourceModule

imports: codecs • encodings

imported by: ecu_dashboard.py • encodings

encodings.iso8859_9 SourceModule

imports: codecs • encodings

imported by: ecu_dashboard.py • encodings

encodings.johab SourceModule

imports: _codecs_kr • _multibytecodec • codecs • encodings

imported by: ecu_dashboard.py • encodings

encodings.koi8_r SourceModule

imports: codecs • encodings

imported by: ecu_dashboard.py • encodings

encodings.koi8_t SourceModule

imports: codecs • encodings

imported by: ecu_dashboard.py • encodings

encodings.koi8_u SourceModule

imports: codecs • encodings

imported by: ecu_dashboard.py • encodings

encodings.kz1048 SourceModule

imports: codecs • encodings

imported by: ecu_dashboard.py • encodings

encodings.latin_1 SourceModule

imports: codecs • encodings

imported by: ecu_dashboard.py • encodings

encodings.mac_arabic SourceModule

imports: codecs • encodings

imported by: ecu_dashboard.py • encodings

encodings.mac_croatian SourceModule

imports: codecs • encodings

imported by: ecu_dashboard.py • encodings

encodings.mac_cyrillic SourceModule

imports: codecs • encodings

imported by: ecu_dashboard.py • encodings

encodings.mac_farsi SourceModule

imports: codecs • encodings

imported by: ecu_dashboard.py • encodings

encodings.mac_greek SourceModule

imports: codecs • encodings

imported by: ecu_dashboard.py • encodings

encodings.mac_iceland SourceModule

imports: codecs • encodings

imported by: ecu_dashboard.py • encodings

encodings.mac_latin2 SourceModule

imports: codecs • encodings

imported by: ecu_dashboard.py • encodings

encodings.mac_roman SourceModule

imports: codecs • encodings

imported by: ecu_dashboard.py • encodings

encodings.mac_romanian SourceModule

imports: codecs • encodings

imported by: ecu_dashboard.py • encodings

encodings.mac_turkish SourceModule

imports: codecs • encodings

imported by: ecu_dashboard.py • encodings

encodings.mbcs SourceModule

imports: codecs • encodings

imported by: ecu_dashboard.py • encodings

encodings.oem SourceModule

imports: codecs • encodings

imported by: ecu_dashboard.py • encodings

encodings.palmos SourceModule

imports: codecs • encodings

imported by: ecu_dashboard.py • encodings

encodings.ptcp154 SourceModule

imports: codecs • encodings

imported by: ecu_dashboard.py • encodings

encodings.punycode SourceModule

imports: codecs • encodings

imported by: ecu_dashboard.py • encodings

encodings.quopri_codec SourceModule

imports: codecs • encodings • io • quopri

imported by: ecu_dashboard.py • encodings

encodings.raw_unicode_escape SourceModule

imports: codecs • encodings

imported by: ecu_dashboard.py • encodings

encodings.rot_13 SourceModule

imports: codecs • encodings • sys

imported by: ecu_dashboard.py • encodings

encodings.shift_jis SourceModule

imports: _codecs_jp • _multibytecodec • codecs • encodings

imported by: ecu_dashboard.py • encodings

encodings.shift_jis_2004 SourceModule

imports: _codecs_jp • _multibytecodec • codecs • encodings

imported by: ecu_dashboard.py • encodings

encodings.shift_jisx0213 SourceModule

imports: _codecs_jp • _multibytecodec • codecs • encodings

imported by: ecu_dashboard.py • encodings

encodings.tis_620 SourceModule

imports: codecs • encodings

imported by: ecu_dashboard.py • encodings

encodings.undefined SourceModule

imports: codecs • encodings

imported by: ecu_dashboard.py • encodings

encodings.unicode_escape SourceModule

imports: codecs • encodings

imported by: ecu_dashboard.py • encodings

encodings.utf_16 SourceModule

imports: codecs • encodings • sys

imported by: ecu_dashboard.py • encodings

encodings.utf_16_be SourceModule

imports: codecs • encodings

imported by: ecu_dashboard.py • encodings

encodings.utf_16_le SourceModule

imports: codecs • encodings

imported by: ecu_dashboard.py • encodings

encodings.utf_32 SourceModule

imports: codecs • encodings • sys

imported by: ecu_dashboard.py • encodings

encodings.utf_32_be SourceModule

imports: codecs • encodings

imported by: ecu_dashboard.py • encodings

encodings.utf_32_le SourceModule

imports: codecs • encodings

imported by: ecu_dashboard.py • encodings

encodings.utf_7 SourceModule

imports: codecs • encodings

imported by: ecu_dashboard.py • encodings

encodings.utf_8 SourceModule

imports: codecs • encodings

imported by: ecu_dashboard.py • encodings

encodings.utf_8_sig SourceModule

imports: codecs • encodings

imported by: ecu_dashboard.py • encodings

encodings.uu_codec SourceModule

imports: binascii • codecs • encodings • io

imported by: ecu_dashboard.py • encodings

encodings.zlib_codec SourceModule

imports: codecs • encodings • zlib

imported by: ecu_dashboard.py • encodings

enum SourceModule

imports: builtins • functools • sys • types • warnings

imported by: ast • calendar • ecu_dashboard.py • inspect • py_compile • re • signal • socket • tkinter

errno (builtin module)

imported by: gettext • gzip • pathlib._abc • posixpath • serial.serialposix • shutil • socket • subprocess • tempfile

fcntl MissingModule

imported by: serial.serialposix • subprocess

fnmatch SourceModule

imports: functools • os • posixpath • re

imported by: glob • shutil • tracemalloc

fractions SourceModule

imports: decimal • functools • math • numbers • operator • re • sys

imported by: statistics

functools SourceModule

imports: _functools • _thread • abc • collections • reprlib • types • typing • warnings • weakref

imported by: contextlib • copyreg • ecu_dashboard.py • email._encoded_words • email.charset • enum • fnmatch • fractions • glob • importlib.metadata • importlib.metadata._adapters • importlib.metadata._functools • importlib.resources._common • inspect • ipaddress • locale • operator • pathlib._abc • pickle • re • statistics • tempfile • tokenize • tracemalloc • types • typing • urllib.parse • warnings

gc (builtin module)

imports: time

imported by: _posixsubprocess • weakref

genericpath SourceModule

imports: os • stat

imported by: ecu_dashboard.py • ntpath • posixpath

getopt SourceModule

imports: gettext • os • sys

imported by: base64 • quopri

gettext SourceModule

imports: builtins • copy • errno • locale • operator • os • re • struct • sys • warnings

imported by: argparse • getopt

glob SourceModule

imports: contextlib • fnmatch • functools • itertools • operator • os • re • stat • sys • warnings

imported by: pathlib._abc • pathlib._local • serial.tools.list_ports_common • serial.tools.list_ports_linux • serial.tools.list_ports_posix

grp MissingModule

imported by: pathlib._local • shutil • subprocess • tarfile

gzip SourceModule

imports: _compression • argparse • builtins • errno • io • os • struct • sys • time • warnings • weakref • zlib

imported by: tarfile

hashlib SourceModule

imports: _blake2 • _hashlib • _md5 • _sha1 • _sha2 • _sha3 • logging

imported by: random

heapq SourceModule

imports: _heapq

imported by: collections • ecu_dashboard.py • queue

importlib Package

imports: _frozen_importlib • _frozen_importlib_external • _imp • importlib • importlib._bootstrap • importlib._bootstrap_external • sys

imported by: importlib • importlib._abc • importlib._bootstrap • importlib._bootstrap_external • importlib.abc • importlib.machinery • importlib.metadata • importlib.readers • importlib.resources • importlib.resources._common • importlib.util • inspect • serial

importlib._abc SourceModule

imports: abc • importlib • importlib._bootstrap

imported by: importlib.abc • importlib.util

importlib._bootstrap SourceModule

imports: _frozen_importlib_external • importlib

imported by: importlib • importlib._abc • importlib.machinery • importlib.util

importlib._bootstrap_external SourceModule

imports: _imp • _io • _warnings • importlib • importlib.metadata • importlib.readers • marshal • nt • posix • sys • tokenize • winreg

imported by: importlib • importlib.abc • importlib.machinery • importlib.util • py_compile

importlib.abc SourceModule

imports: _frozen_importlib • _frozen_importlib_external • abc • importlib • importlib._abc • importlib._bootstrap_external • importlib.machinery • importlib.resources • importlib.resources.abc • warnings

imported by: importlib.metadata

importlib.machinery SourceModule

imports: importlib • importlib._bootstrap • importlib._bootstrap_external

imported by: importlib.abc • inspect • py_compile • sysconfig

importlib.metadata Package

imports: __future__ • abc • collections • contextlib • csv • email • functools • importlib • importlib.abc • importlib.metadata • importlib.metadata._adapters • importlib.metadata._collections • importlib.metadata._functools • importlib.metadata._itertools • importlib.metadata._meta • inspect • itertools • json • operator • os • pathlib • posixpath • re • sys • textwrap • types • typing • warnings • zipfile

imported by: importlib._bootstrap_external • importlib.metadata • importlib.metadata._adapters • importlib.metadata._collections • importlib.metadata._functools • importlib.metadata._itertools • importlib.metadata._meta • importlib.metadata._text

importlib.metadata._adapters SourceModule

imports: email.message • functools • importlib.metadata • importlib.metadata._text • re • textwrap • warnings

imported by: importlib.metadata

importlib.metadata._collections SourceModule

imports: collections • importlib.metadata

imported by: importlib.metadata

importlib.metadata._functools SourceModule

imports: functools • importlib.metadata • types

imported by: importlib.metadata • importlib.metadata._text

importlib.metadata._itertools SourceModule

imports: importlib.metadata • itertools

imported by: importlib.metadata

importlib.metadata._meta SourceModule

imports: __future__ • importlib.metadata • os • typing

imported by: importlib.metadata

importlib.metadata._text SourceModule

imports: importlib.metadata • importlib.metadata._functools • re

imported by: importlib.metadata._adapters

importlib.readers SourceModule

imports: importlib • importlib.resources.readers

imported by: importlib._bootstrap_external

importlib.resources Package

imports: importlib • importlib.resources • importlib.resources._common • importlib.resources._functional • importlib.resources.abc

imported by: importlib.abc • importlib.resources • importlib.resources._adapters • importlib.resources._common • importlib.resources._functional • importlib.resources._itertools • importlib.resources.abc • importlib.resources.readers

importlib.resources._adapters SourceModule

imports: contextlib • importlib.resources • importlib.resources.abc • io

imported by: importlib.resources._common

importlib.resources._common SourceModule

imports: contextlib • functools • importlib • importlib.resources • importlib.resources._adapters • importlib.resources.abc • inspect • itertools • os • pathlib • tempfile • types • typing • warnings

imported by: importlib.resources • importlib.resources._functional

importlib.resources._functional SourceModule

imports: importlib.resources • importlib.resources._common • warnings

imported by: importlib.resources

importlib.resources._itertools SourceModule

imports: importlib.resources

imported by: importlib.resources.readers

importlib.resources.abc SourceModule

imports: abc • importlib.resources • io • itertools • os • pathlib • typing

imported by: importlib.abc • importlib.resources • importlib.resources._adapters • importlib.resources._common • importlib.resources.readers

importlib.resources.readers SourceModule

imports: 'collections.abc' • __future__ • collections • contextlib • importlib.resources • importlib.resources._itertools • importlib.resources.abc • itertools • operator • pathlib • re • warnings • zipfile

imported by: importlib.readers

importlib.util SourceModule

imports: _imp • importlib • importlib._abc • importlib._bootstrap • importlib._bootstrap_external • sys • threading • types

imported by: py_compile • sysconfig • zipfile

inspect SourceModule

imports: 'collections.abc' • abc • argparse • ast • builtins • collections • dis • enum • functools • importlib • importlib.machinery • itertools • keyword • linecache • operator • os • re • sys • token • tokenize • types • typing • weakref

imported by: ast • dataclasses • importlib.metadata • importlib.resources._common • pyi_rth_inspect.py • typing • warnings

io SourceModule

imports: _io • abc

imported by: _compression • base64 • bz2 • csv • dis • ecu_dashboard.py • email.feedparser • email.generator • email.iterators • email.message • email.parser • encodings.quopri_codec • encodings.uu_codec • gzip • importlib.resources._adapters • importlib.resources.abc • logging • lzma • os • pathlib._local • pickle • pprint • quopri • serial.serialutil • socket • subprocess • tarfile • tempfile • tokenize • zipfile • zipfile._path

ipaddress SourceModule

imports: functools • re

imported by: urllib.parse

itertools (builtin module)

imported by: _pydecimal • calendar • collections • dataclasses • glob • importlib.metadata • importlib.metadata._itertools • importlib.resources._common • importlib.resources.abc • importlib.resources.readers • inspect • pathlib._local • pickle • random • reprlib • statistics • threading • tokenize • traceback • weakref • zipfile._path

json Package

imports: codecs • json.decoder • json.encoder • json.scanner

imported by: importlib.metadata • json.decoder • json.encoder • json.scanner

json.decoder SourceModule

imports: _json • json • json.scanner • re

imported by: _json • json

json.encoder SourceModule

imports: _json • json • re

imported by: json

json.scanner SourceModule

imports: _json • json • re

imported by: json • json.decoder

keyword SourceModule

imported by: collections • dataclasses • ecu_dashboard.py • inspect

linecache SourceModule

imports: os • sys • tokenize

imported by: ecu_dashboard.py • inspect • traceback • tracemalloc • warnings

locale SourceModule

imports: _collections_abc • _locale • builtins • encodings • encodings.aliases • functools • os • re • sys • warnings

imported by: _pydecimal • _strptime • calendar • ecu_dashboard.py • gettext • subprocess

logging Package

imports: 'collections.abc' • atexit • io • os • pickle • re • string • sys • threading • time • traceback • types • warnings • weakref

imported by: hashlib

lzma SourceModule

imports: _compression • _lzma • builtins • io • os

imported by: shutil • tarfile • zipfile

marshal (builtin module)

imported by: importlib._bootstrap_external

math (builtin module)

imported by: _pydatetime • _pydecimal • fractions • random • reprlib • selectors • statistics • urllib.parse

msvcrt (builtin module)

imported by: subprocess

nt (builtin module)

imported by: _colorize • ctypes • importlib._bootstrap_external • ntpath • os • shutil

ntpath SourceModule

imports: _winapi • genericpath • nt • os • re • sys

imported by: ecu_dashboard.py • os • os.path • pathlib._local

numbers SourceModule

imports: abc

imported by: _pydecimal • fractions • statistics

opcode SourceModule

imports: _opcode • _opcode_metadata

imported by: dis

operator SourceModule

imports: _operator • builtins • functools

imported by: _pydatetime • collections • copyreg • ecu_dashboard.py • email._header_value_parser • fractions • gettext • glob • importlib.metadata • importlib.resources.readers • inspect • pathlib._local • random • statistics • typing

os SourceModule

imports: _collections_abc • abc • io • nt • ntpath • os.path • posix • posixpath • stat • subprocess • sys • warnings

imported by: _aix_support • _colorize • _strptime • argparse • bz2 • contextlib • ctypes • ecu_dashboard.py • email.utils • fnmatch • genericpath • getopt • gettext • glob • gzip • importlib.metadata • importlib.metadata._meta • importlib.resources._common • importlib.resources.abc • inspect • linecache • locale • logging • lzma • ntpath • os.path • pathlib._local • posixpath • py_compile • pyi_rth__tkinter.py • pyi_rth_inspect.py • random • serial • serial.serialposix • serial.tools.list_ports • serial.tools.list_ports_common • serial.tools.list_ports_linux • serial.tools.list_ports_posix • shutil • socket • subprocess • sysconfig • tarfile • tempfile • threading • tkinter • zipfile • zipfile._path.glob

os.path AliasNode

imports: ntpath • os

imported by: os • py_compile • serial.tools.list_ports_common • sysconfig • tracemalloc

pathlib Package

imports: pathlib._abc • pathlib._local

imported by: importlib.metadata • importlib.resources._common • importlib.resources.abc • importlib.resources.readers • pathlib._abc • pathlib._local • zipfile._path

pathlib._abc SourceModule

imports: errno • functools • glob • pathlib • stat

imported by: pathlib • pathlib._local

pathlib._local SourceModule

imports: _collections_abc • glob • grp • io • itertools • ntpath • operator • os • pathlib • pathlib._abc • posixpath • pwd • sys • urllib.parse • warnings

imported by: pathlib

pickle SourceModule

imports: _compat_pickle • _pickle • codecs • copyreg • functools • io • itertools • pprint • re • struct • sys • types

imported by: logging • tracemalloc

posix MissingModule

imports: resource

imported by: importlib._bootstrap_external • os • posixpath • shutil

posixpath SourceModule

imports: errno • genericpath • os • posix • pwd • re • stat • sys

imported by: ecu_dashboard.py • fnmatch • importlib.metadata • os • pathlib._local • zipfile._path

pprint SourceModule

imports: collections • dataclasses • io • re • sys • types

imported by: pickle

pwd MissingModule

imported by: pathlib._local • posixpath • shutil • subprocess • tarfile

py_compile SourceModule

imports: argparse • enum • importlib._bootstrap_external • importlib.machinery • importlib.util • os • os.path • sys • traceback

imported by: zipfile

queue SourceModule

imports: _queue • collections • heapq • threading • time • types

imported by: ecu_dashboard.py

quopri SourceModule

imports: binascii • getopt • io • sys

imported by: email.encoders • email.message • encodings.quopri_codec

random SourceModule

imports: _collections_abc • _random • _sha2 • argparse • bisect • hashlib • itertools • math • operator • os • statistics • time • warnings

imported by: email.generator • email.utils • statistics • tempfile

re Package

imports: _sre • copyreg • enum • functools • re • re._compiler • re._constants • re._parser • warnings

imported by: _pydecimal • _sre • _strptime • argparse • ast • base64 • csv • dataclasses • ecu_dashboard.py • email._encoded_words • email._header_value_parser • email.feedparser • email.generator • email.header • email.message • email.policy • email.quoprimime • email.utils • encodings.idna • fnmatch • fractions • gettext • glob • importlib.metadata • importlib.metadata._adapters • importlib.metadata._text • importlib.resources.readers • inspect • ipaddress • json.decoder • json.encoder • json.scanner • locale • logging • ntpath • pickle • posixpath • pprint • re • re._casefix • re._compiler • re._constants • re._parser • serial.tools.list_ports • serial.tools.list_ports_common • serial.tools.list_ports_windows • sre_compile • sre_constants • sre_parse • string • sysconfig • tarfile • textwrap • tkinter • tokenize • typing • urllib.parse • warnings • zipfile._path • zipfile._path.glob

re._casefix SourceModule

imports: re

imported by: ecu_dashboard.py • re._compiler

re._compiler SourceModule

imports: _sre • re • re._casefix • re._constants • re._parser • sys

imported by: ecu_dashboard.py • re • sre_compile

re._constants SourceModule

imports: _sre • re

imported by: ecu_dashboard.py • re • re._compiler • re._parser • sre_constants

re._parser SourceModule

imports: re • re._constants • unicodedata • warnings

imported by: ecu_dashboard.py • re • re._compiler • sre_parse

reprlib SourceModule

imports: _thread • builtins • itertools • math • sys

imported by: collections • dataclasses • ecu_dashboard.py • functools

resource MissingModule

imported by: posix

select C:\Users\owen.maute\AppData\Local\Programs\Python\Python313\DLLs\select.pyd

imported by: selectors • serial.serialposix • subprocess

selectors SourceModule

imports: 'collections.abc' • abc • collections • math • select • sys

imported by: socket • subprocess

serial Package

imports: __future__ • importlib • os • serial.serialcli • serial.serialjava • serial.serialposix • serial.serialutil • serial.serialwin32 • serial.win32 • sys

imported by: ecu_dashboard.py • serial.serialcli • serial.serialjava • serial.serialposix • serial.serialutil • serial.serialwin32 • serial.tools • serial.tools.list_ports_posix • serial.tools.list_ports_windows • serial.win32

serial.serialcli SourceModule

imports: 'System.IO' • System • __future__ • serial • serial.serialutil

imported by: serial

serial.serialjava SourceModule

imports: __future__ • serial • serial.serialutil

imported by: serial

serial.serialposix SourceModule

imports: __future__ • array • errno • fcntl • os • select • serial • serial.serialutil • struct • sys • termios • warnings

imported by: serial

serial.serialutil SourceModule

imports: __future__ • array • io • serial • sys • time

imported by: serial • serial.serialcli • serial.serialjava • serial.serialposix • serial.serialwin32

serial.serialwin32 SourceModule

imports: __future__ • ctypes • serial • serial.serialutil • serial.win32 • time

imported by: serial

serial.tools Package

imports: serial • serial.tools.list_ports_common

imported by: serial.tools.list_ports • serial.tools.list_ports_common • serial.tools.list_ports_linux • serial.tools.list_ports_osx • serial.tools.list_ports_posix • serial.tools.list_ports_windows

serial.tools.list_ports SourceModule

imports: __future__ • argparse • os • re • serial.tools • serial.tools.list_ports_posix • serial.tools.list_ports_windows • sys

imported by: ecu_dashboard.py

serial.tools.list_ports_common SourceModule

imports: __future__ • glob • os • os.path • re • serial.tools

imported by: serial.tools • serial.tools.list_ports_linux • serial.tools.list_ports_osx • serial.tools.list_ports_posix • serial.tools.list_ports_windows

serial.tools.list_ports_linux SourceModule

imports: __future__ • glob • os • serial.tools • serial.tools.list_ports_common

imported by: serial.tools.list_ports_posix

serial.tools.list_ports_osx SourceModule

imports: __future__ • ctypes • serial.tools • serial.tools.list_ports_common

imported by: serial.tools.list_ports_posix

serial.tools.list_ports_posix SourceModule

imports: __future__ • glob • os • serial • serial.tools • serial.tools.list_ports_common • serial.tools.list_ports_linux • serial.tools.list_ports_osx • sys

imported by: serial.tools.list_ports

serial.tools.list_ports_windows SourceModule

imports: __future__ • ctypes • ctypes.wintypes • re • serial • serial.tools • serial.tools.list_ports_common • serial.win32

imported by: serial.tools.list_ports

serial.win32 SourceModule

imports: __future__ • ctypes • ctypes.wintypes • serial

imported by: serial • serial.serialwin32 • serial.tools.list_ports_windows

shutil SourceModule

imports: _winapi • bz2 • collections • errno • fnmatch • grp • lzma • nt • os • posix • pwd • stat • sys • tarfile • zipfile • zlib

imported by: argparse • tarfile • tempfile • zipfile

signal SourceModule

imports: _signal • enum

imported by: subprocess

socket SourceModule

imports: _socket • array • enum • errno • io • os • selectors • sys

imported by: email.utils

sre_compile SourceModule

imports: re • re._compiler • warnings

imported by: ecu_dashboard.py

sre_constants SourceModule

imports: re • re._constants • warnings

imported by: ecu_dashboard.py

sre_parse SourceModule

imports: re • re._parser • warnings

imported by: ecu_dashboard.py

stat SourceModule

imports: _stat

imported by: ecu_dashboard.py • genericpath • glob • os • pathlib._abc • posixpath • shutil • tarfile • zipfile • zipfile._path

statistics SourceModule

imports: _statistics • bisect • collections • decimal • fractions • functools • itertools • math • numbers • operator • random • sys

imported by: random

string SourceModule

imports: _string • collections • re

imported by: email._encoded_words • email._header_value_parser • email.quoprimime • logging

stringprep SourceModule

imports: unicodedata

imported by: encodings.idna

struct SourceModule

imports: _struct

imported by: base64 • ctypes • gettext • gzip • pickle • serial.serialposix • tarfile • zipfile

subprocess SourceModule

imports: _posixsubprocess • _winapi • builtins • contextlib • errno • fcntl • grp • io • locale • msvcrt • os • pwd • select • selectors • signal • sys • threading • time • types • warnings

imported by: _aix_support • os

sys (builtin module)

imported by: _aix_support • _collections_abc • _colorize • _compression • _pydatetime • _pydecimal • argparse • ast • base64 • calendar • codecs • collections • contextlib • ctypes • ctypes._endian • dataclasses • decimal • dis • email._header_value_parser • email.contentmanager • email.generator • email.iterators • email.policy • encodings • encodings.rot_13 • encodings.utf_16 • encodings.utf_32 • enum • fractions • getopt • gettext • glob • gzip • importlib • importlib._bootstrap_external • importlib.metadata • importlib.util • inspect • linecache • locale • logging • ntpath • os • pathlib._local • pickle • posixpath • pprint • py_compile • pyi_rth__tkinter.py • pyi_rth_inspect.py • quopri • re._compiler • reprlib • selectors • serial • serial.serialposix • serial.serialutil • serial.tools.list_ports • serial.tools.list_ports_posix • shutil • socket • statistics • subprocess • sysconfig • tarfile • tempfile • threading • tkinter • tokenize • traceback • types • typing • warnings • weakref • zipfile • zipfile._path

sysconfig Package

imports: _aix_support • _sysconfig • _winapi • importlib.machinery • importlib.util • os • os.path • re • sys • threading • warnings

imported by: _aix_support • ctypes

tarfile SourceModule

imports: argparse • builtins • bz2 • copy • grp • gzip • io • lzma • os • pwd • re • shutil • stat • struct • sys • time • warnings • zlib

imported by: shutil

tempfile SourceModule

imports: _thread • errno • functools • io • os • random • shutil • sys • types • warnings • weakref

imported by: importlib.resources._common

termios MissingModule

imported by: serial.serialposix

textwrap SourceModule

imports: re

imported by: argparse • importlib.metadata • importlib.metadata._adapters • traceback

threading SourceModule

imports: _collections • _thread • _threading_local • _weakrefset • collections • itertools • os • sys • time • traceback • warnings

imported by: _threading_local • ecu_dashboard.py • importlib.util • logging • queue • subprocess • sysconfig • zipfile

time (builtin module)

imports: _strptime

imported by: _datetime • _pydatetime • _strptime • datetime • ecu_dashboard.py • email._parseaddr • email.generator • email.utils • gc • gzip • logging • queue • random • serial.serialutil • serial.serialwin32 • subprocess • tarfile • threading • zipfile

tkinter Package

imports: _tkinter • collections • enum • os • re • sys • tkinter.constants • tkinter.messagebox • tkinter.scrolledtext • tkinter.ttk • traceback • types

imported by: ecu_dashboard.py • tkinter.commondialog • tkinter.constants • tkinter.messagebox • tkinter.scrolledtext • tkinter.ttk

tkinter.commondialog SourceModule

imports: tkinter

imported by: tkinter.messagebox

tkinter.constants SourceModule

imports: tkinter

imported by: tkinter • tkinter.scrolledtext

tkinter.messagebox SourceModule

imports: tkinter • tkinter.commondialog

imported by: ecu_dashboard.py • tkinter

tkinter.scrolledtext SourceModule

imports: tkinter • tkinter.constants

imported by: ecu_dashboard.py • tkinter

tkinter.ttk SourceModule

imports: tkinter

imported by: ecu_dashboard.py • tkinter

token SourceModule

imported by: inspect • tokenize

tokenize SourceModule

imports: _tokenize • argparse • builtins • codecs • collections • functools • io • itertools • re • sys • token

imported by: importlib._bootstrap_external • inspect • linecache

traceback SourceModule

imports: 'collections.abc' • _colorize • _suggestions • ast • contextlib • itertools • linecache • sys • textwrap • unicodedata • warnings

imported by: ecu_dashboard.py • logging • py_compile • threading • tkinter • warnings

tracemalloc SourceModule

imports: 'collections.abc' • _tracemalloc • fnmatch • functools • linecache • os.path • pickle

imported by: warnings

types SourceModule

imports: _collections_abc • _socket • functools • sys

imported by: _weakrefset • contextlib • copy • csv • ctypes • dataclasses • dis • ecu_dashboard.py • email.headerregistry • enum • functools • importlib.metadata • importlib.metadata._functools • importlib.resources._common • importlib.util • inspect • logging • pickle • pprint • queue • subprocess • tempfile • tkinter • typing • urllib.parse • warnings

typing SourceModule

imports: 'collections.abc' • _typing • abc • collections • contextlib • copyreg • functools • inspect • operator • re • sys • types • warnings

imported by: _colorize • functools • importlib.metadata • importlib.metadata._meta • importlib.resources._common • importlib.resources.abc • inspect

unicodedata C:\Users\owen.maute\AppData\Local\Programs\Python\Python313\DLLs\unicodedata.pyd

imported by: encodings.idna • re._parser • stringprep • traceback • urllib.parse

urllib Package

imported by: email._header_value_parser • urllib.parse

urllib.parse SourceModule

imports: collections • functools • ipaddress • math • re • types • unicodedata • urllib • warnings

imported by: email.utils • pathlib._local

warnings SourceModule

imports: _warnings • builtins • functools • inspect • linecache • re • sys • traceback • tracemalloc • types

imported by: _collections_abc • _pydatetime • _strptime • argparse • ast • calendar • ctypes • ecu_dashboard.py • email.utils • enum • functools • gettext • glob • gzip • importlib.abc • importlib.metadata • importlib.metadata._adapters • importlib.resources._common • importlib.resources._functional • importlib.resources.readers • locale • logging • os • pathlib._local • random • re • re._parser • serial.serialposix • sre_compile • sre_constants • sre_parse • subprocess • sysconfig • tarfile • tempfile • threading • traceback • typing • urllib.parse • zipfile

weakref SourceModule

imports: _collections_abc • _weakref • _weakrefset • atexit • copy • gc • itertools • sys

imported by: _threading_local • copy • ecu_dashboard.py • functools • gzip • inspect • logging • tempfile

winreg (builtin module)

imported by: importlib._bootstrap_external

zipfile Package

imports: argparse • binascii • bz2 • importlib.util • io • lzma • os • py_compile • shutil • stat • struct • sys • threading • time • warnings • zipfile._path • zlib

imported by: importlib.metadata • importlib.resources.readers • pyi_rth_inspect.py • shutil • zipfile._path

zipfile._path Package

imports: contextlib • io • itertools • pathlib • posixpath • re • stat • sys • zipfile • zipfile._path.glob

imported by: zipfile • zipfile._path.glob

zipfile._path.glob SourceModule

imports: os • re • zipfile._path

imported by: zipfile._path

zlib (builtin module)

imported by: encodings.zlib_codec • gzip • shutil • tarfile • zipfile

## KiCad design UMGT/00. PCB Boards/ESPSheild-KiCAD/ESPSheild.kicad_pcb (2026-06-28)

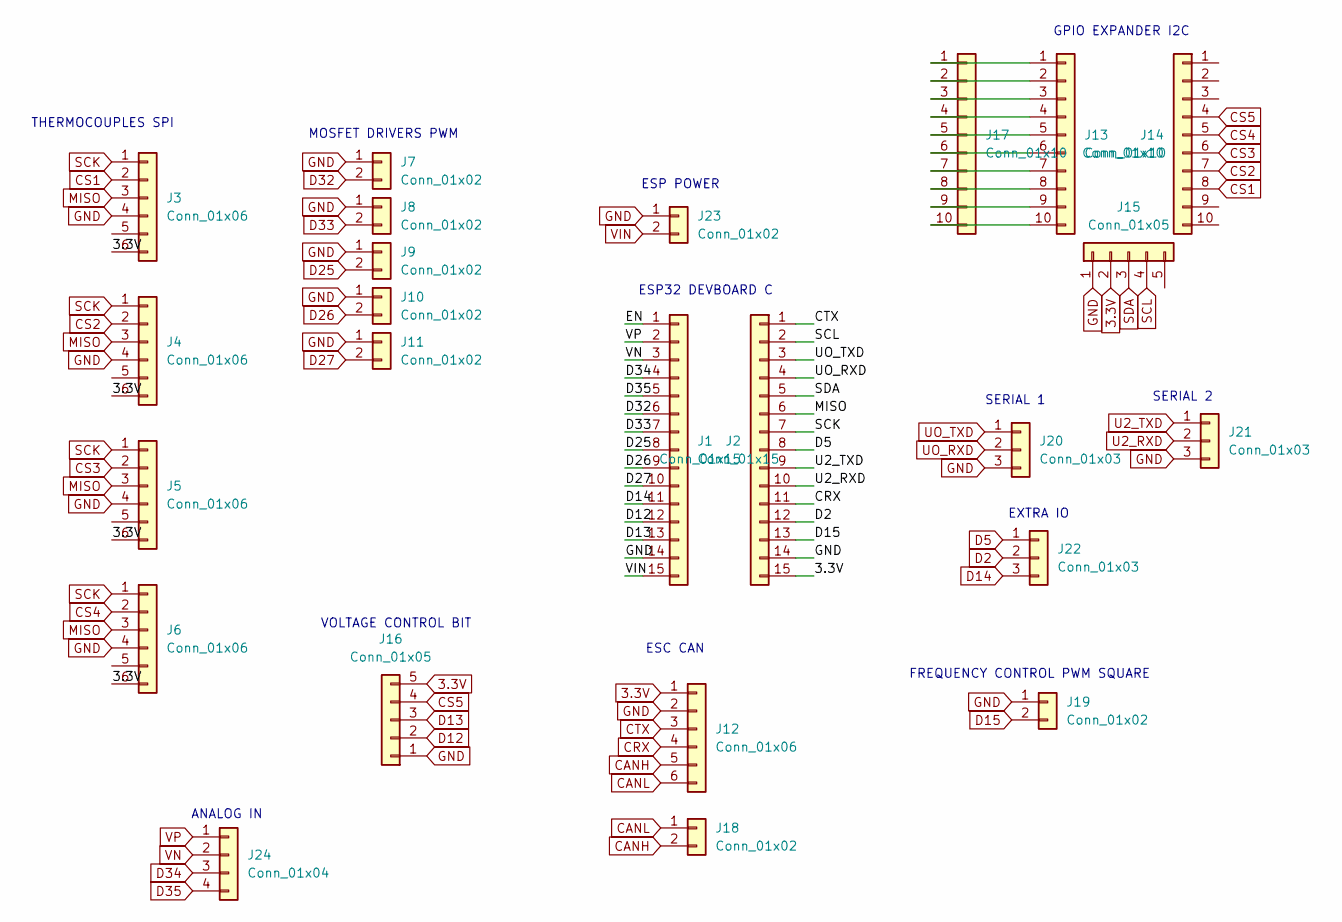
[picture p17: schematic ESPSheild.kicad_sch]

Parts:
J1, J2: Conn_01x15; PinSocket_1x15_P2.54mm_Vertical
J3, J4, J5, J6, J12: Conn_01x06; PinSocket_1x06_P2.54mm_Vertical
J7, J8, J9, J10, J11, J18, J19, J23: Conn_01x02; AMASS_XT30UPB-M_1x02_P5.0mm_Vertical
J13, J14, J17: Conn_01x10; PinHeader_1x10_P2.54mm_Vertical
J15: Conn_01x05; PinHeader_1x05_P2.54mm_Vertical
J16: Conn_01x05; PinSocket_1x05_P2.54mm_Vertical
J20, J21: Conn_01x03; Molex_KK-396_A-41791-0003_1x03_P3.96mm_Vertical
J22: Conn_01x03; PinHeader_1x03_P2.54mm_Vertical
J24: Conn_01x04; PinHeader_1x04_P2.54mm_Vertical

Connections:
3.3V: J2.15, J3.6, J4.6, J5.6, J6.6, J12.1, J15.2, J16.5
/EN: J1.1
CANH: J12.5, J18.2
CANL: J12.6, J18.1
CRX: J2.11, J12.4
CS1: J3.2, J14.8
CS2: J4.2, J14.7
CS3: J5.2, J14.6
CS4: J6.2, J14.5
CS5: J14.4, J16.4
CTX: J2.1, J12.3
D2: J2.12, J22.2
D5: J2.8, J22.1
D12: J1.12, J16.2
D13: J1.13, J16.3
D14: J1.11, J22.3
D15: J2.13, J19.2
D25: J1.8, J9.2
D26: J1.9, J10.2
D27: J1.10, J11.2
D32: J1.6, J7.2
D33: J1.7, J8.2
D34: J1.4, J24.3
D35: J1.5, J24.4
GND: J1.14, J2.14, J3.4, J4.4, J5.4, J6.4, J7.1, J8.1, J9.1, J10.1, J11.1, J12.2, J15.1, J16.1, J19.1, J20.3, J21.3, J23.1
MISO: J2.6, J3.3, J4.3, J5.3, J6.3
unnamed: J13.1, J17.1
unnamed: J13.2, J17.2
unnamed: J13.3, J17.3
unnamed: J13.4, J17.4
unnamed: J13.5, J17.5
unnamed: J13.6, J17.6
unnamed: J13.7, J17.7
unnamed: J13.8, J17.8
unnamed: J13.9, J17.9
unnamed: J13.10, J17.10
SCK: J2.7, J3.1, J4.1, J5.1, J6.1
SCL: J2.2, J15.4
SDA: J2.5, J15.3
U2_RXD: J2.10, J21.2
U2_TXD: J2.9, J21.1
UO_RXD: J2.4, J20.2
UO_TXD: J2.3, J20.1
VIN: J1.15, J23.2
VN: J1.3, J24.2
VP: J1.2, J24.1

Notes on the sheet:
ESC CAN
VOLTAGE CONTROL BIT
FREQUENCY CONTROL PWM SQUARE
ESP32 DEVBOARD C
MOSFET DRIVERS PWM
ANALOG IN
ESP POWER
THERMOCOUPLES SPI
SERIAL 2
GPIO EXPANDER I2C
EXTRA IO
SERIAL 1

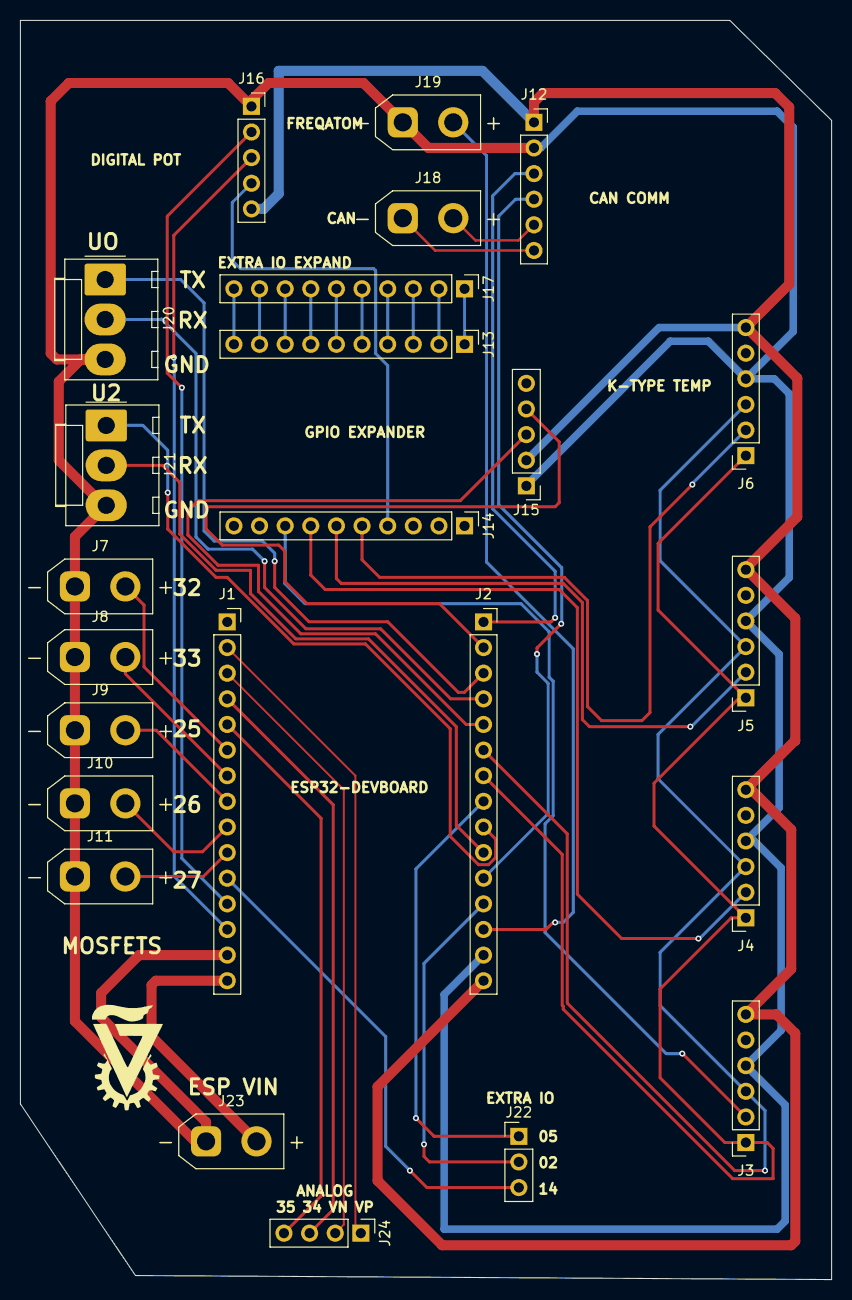
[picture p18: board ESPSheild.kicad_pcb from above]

Board: 2 copper layers, 80.4 x 124.8 mm, 25 parts (0 on the bottom side), 45 nets.

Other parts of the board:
g**: LOGO

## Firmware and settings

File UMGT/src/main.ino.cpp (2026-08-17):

#include <Arduino.h>
#include <Wire.h>
#include <SPI.h>
#include <math.h>
#include <Preferences.h>
#include "driver/twai.h"
#include "esp_system.h"

// -----------------------------------------------------------------------------
// Pin map — verified against ESPSheild-KiCAD netlist (J1/J2 DevKitC-32 headers)
// -----------------------------------------------------------------------------
// U0 (Serial / USB)  → debug terminal, EXE connects here (J20 breakout, SERIAL 1)
// U2 (Serial2)       → Pixhawk telemetry (J21, SERIAL 2)
#define DEBUG_BAUD        115200
#define ECU_SERIAL_BAUD   115200

// Pixhawk MAVLink UART on J21 / SERIAL 2 (U2). Solid keyed 3-pin connector.
//   Cube TELEM1 TX (pin 2) -> U2 RX (GPIO16),  Cube RX (pin 3) -> U2 TX (GPIO17).
#define PIN_UART2_RX      16   // U2_RXD (J21)
#define PIN_UART2_TX      17   // U2_TXD (J21)

// CAN / TWAI → ESC via SN65HVD230 on J12 (3V3, GND, CTX, CRX, CANH, CANL)
// The ESC is a Hargrave microDRIVE LPi speaking DroneCAN (UAVCAN v0),
// standard bitrate 1 Mbps.
#define PIN_CAN_TX        23   // net CTX (J2 pad 1)
#define PIN_CAN_RX        4    // net CRX (J2 pad 11)
#define CAN_DEFAULT_KBPS  1000

// DroneCAN identifiers
#define DC_NODE_ID_SELF     100   // our node id when transmitting
#define DTID_ALLOCATION     1     // uavcan.protocol.dynamic_node_id.Allocation
#define SIG_ALLOCATION      0x0B2A812620A11D40ULL
#define DNA_DEFAULT_NODE_ID 125   // handed to the ESC if it has no preference
#define DTID_NODE_STATUS    341   // uavcan.protocol.NodeStatus (1 Hz heartbeat)
#define DTID_ARMING_STATUS  1100  // uavcan.equipment.safety.ArmingStatus
#define SIG_ARMING_STATUS   0x8700F375556A8003ULL

// DroneCAN services (for configuring the microDRIVE over the bus)
#define SVC_GETSET          11    // uavcan.protocol.param.GetSet
#define SIG_SVC_GETSET      0xA7B622F939D1A4D5ULL
#define SVC_OPCODE          10    // uavcan.protocol.param.ExecuteOpcode
#define SIG_SVC_OPCODE      0x3B131AC5EB69D2CDULL
#define SVC_RESTART         5     // uavcan.protocol.RestartNode
#define SIG_SVC_RESTART     0x569E05394A3017F0ULL
#define RESTART_MAGIC       0xACCE551B1EULL
#define DTID_ESC_RAWCMD     1030  // uavcan.equipment.esc.RawCommand (duty)
#define DTID_ESC_RPMCMD     1031  // uavcan.equipment.esc.RPMCommand (closed loop)
#define DTID_ESC_STATUS     1034  // uavcan.equipment.esc.Status (10 Hz from ESC)
#define SIG_ESC_STATUS      0xA9AF28AEA2FBB254ULL
#define DTID_ESC_STATUS_EXT 1036  // uavcan.equipment.esc.StatusExtended (1 Hz)

// ESC telemetry older than this is dead — omit it from the stream so stale
// values can never masquerade as live readings on the dashboard.
#define ESC_TELEM_TIMEOUT_MS 5000

// SPI (thermocouples, read-only — no MOSI on this board, GPIO23 is CAN TX!)
#define PIN_SPI_SCK       18   // net SCK
#define PIN_SPI_MISO      19   // net MISO

// I2C (PCF8575 expander on J15)
#define PIN_I2C_SDA       21   // net SDA
#define PIN_I2C_SCL       22   // net SCL

// MOSFET PWM outputs (J7..J11: fuel pump, cooling pump, fuel sol, cool sol, glow)
#define PIN_MOSFET_A      32   // J7
#define PIN_MOSFET_B      33   // J8
#define PIN_MOSFET_C      25   // J9
#define PIN_MOSFET_D      26   // J10
#define PIN_MOSFET_E      27   // J11

// X9C digital pot on J16 (GND, U/D, INC, CS, VCC) — "VOLTAGE CONTROL BIT"
#define PIN_POT_UD        12   // net D12 → X9C U/D
#define PIN_POT_INC       13   // net D13 → X9C INC (wiper moves on falling edge)
#define POT_STEPS         100  // X9C103S/X9C503S: 100 wiper positions (0-99)

// Piezo / atomizer driver square wave on J19 — "FREQUENCY CONTROL PWM SQUARE"
#define PIN_PIEZO         15   // net D15

// Analog inputs (J24: VP, VN, D34, D35) — "ANALOG IN"
#define PIN_ANALOG_VP     36   // spare analog
#define PIN_ANALOG_VN     39   // spare analog
#define PIN_ANALOG_A      34   // SSA-2 differential current sensor: OUTP (+Vo)
#define PIN_ANALOG_B      35   // SSA-2 differential current sensor: OUTN (-Vo)

// Spare GPIO on J22 "EXTRA IO": D5, D2, D14 (unused by firmware)

// -----------------------------------------------------------------------------
// PCF8575 expander (I2C 0x20). High byte = P17..P10 → state bits 15..8.
// J14 row wiring (from PCB netlist + module silkscreen):
//   P12 = CS1 = TC1 (TIT)     → bit 10
//   P13 = CS2 = TC2 (EGT)     → bit 11
//   P14 = CS3 = TC3 (Bearing) → bit 12
//   P15 = CS4 = TC4 (Coil)    → bit 13
//   P16 = CS5 = X9C pot CS    → bit 14
// P00..P07 (bits 0-7) are broken out on J13/J17 "EXTRA IO EXPAND".
// All CS lines are active LOW.
// -----------------------------------------------------------------------------
#define I2C_EXPANDER_ADDR     0x20
#define EXP_BIT_TC1       10
#define EXP_BIT_TC2       11
#define EXP_BIT_TC3       12
#define EXP_BIT_TC4       13
#define EXP_BIT_POT_CS    14

static const uint8_t tcExpBits[4] = { EXP_BIT_TC1, EXP_BIT_TC2, EXP_BIT_TC3, EXP_BIT_TC4 };
static const char   *tcNames[4]   = { "TIT", "EGT", "Bearing", "Coil" };

// -----------------------------------------------------------------------------
// PWM (LEDC). Channels 0/1 share timer0, 2/3 timer1, 4/5 timer2, 6/7 timer3.
// Piezo gets channel 0 (timer0 alone). MOSFETs share one frequency so they can
// share timers: channels 2..6. Never mix piezo and MOSFETs on the same timer.
// -----------------------------------------------------------------------------
#define PWM_CHANNEL        0
#define PWM_RESOLUTION     8
#define PWM_DEFAULT_FREQ   2000

#define MOSFET_PWM_FREQ    10000
#define MOSFET_PWM_RESOLUTION 8

// -----------------------------------------------------------------------------
// Current sensor calibration — Bourns SSA-2 shunt sensor, DIFFERENTIAL output.
// Two outputs (OUTP=+Vo on GPIO34, OUTN=-Vo on GPIO35), each sitting at a
// ~1.44 V common-mode referenced to ground. Current is proportional to the
// DIFFERENCE (OUTP - OUTN), read with two single-ended ADCs and subtracted in
// software (datasheet p.6). Zero current = 0 V differential, so the reading is
// bipolar: reverse current flips the sign instead of pinning at 0 V like the
// old hall sensor did.
//   SSA-2-100A  = 12.5 mV/A  -> 80  A/V   (our part; ±208 A before clipping)
//   SSA-2-250A  = 5    mV/A  -> 200 A/V
//   SSA-2-500A  = 2.5  mV/A  -> 400 A/V
//   SSA-2-1000A = 1.25 mV/A  -> 800 A/V
// Each leg swings ±1.3 V max around the 1.44 V CM (0.14..2.74 V), so no divider
// is needed — the whole ±208 A span fits inside the ESP32 ADC. Trim the residual
// differential offset at runtime with: current cal <zero_volts> <amps_per_volt>
// -----------------------------------------------------------------------------
static float currentZeroVolts = 0.0f;   // differential-volt offset at 0 A
static float currentAmpsPerVolt = 80.0f;  // SSA-2-100A: 12.5 mV/A

// Telemetry rates. The MAX31855 converts internally every 70-100ms, so TCs are
// sampled at a fixed 10 Hz (faster polling returns duplicate conversions).
// The stream rate is independent and adjustable 1-50 Hz ("stream rate <hz>").
#define TC_SAMPLE_MS         100
#define STREAM_DEFAULT_HZ    10
static uint32_t streamIntervalMs = 1000 / STREAM_DEFAULT_HZ;

// -----------------------------------------------------------------------------
// State
// -----------------------------------------------------------------------------
static uint32_t mosfetFrequency = MOSFET_PWM_FREQ;

// Load map per Owen (2026-07-08): M1/GPIO32=glow plug, M2/GPIO33=solenoid 2,
// M3/GPIO25=solenoid 1, M4/GPIO26=fuel pump 2, M5/GPIO27=fuel pump 1
static const uint8_t mosfetPins[]     = { PIN_MOSFET_A, PIN_MOSFET_B, PIN_MOSFET_C, PIN_MOSFET_D, PIN_MOSFET_E };
static const uint8_t mosfetChannels[] = { 2, 3, 4, 5, 6 };
static const char   *mosfetNames[]    = { "GlowPlug", "Solenoid2", "Solenoid1", "FuelPump2", "FuelPump1" };

// Engine actuator indices into the mosfet arrays
#define MOSFET_IDX_GLOW   0   // GPIO32
#define MOSFET_IDX_SOL2   1   // GPIO33
#define MOSFET_IDX_SOL1   2   // GPIO25
#define MOSFET_IDX_PUMP2  3   // GPIO26
#define MOSFET_IDX_PUMP1  4   // GPIO27
static const uint8_t pumpMosfetIdx[2] = { MOSFET_IDX_PUMP1, MOSFET_IDX_PUMP2 };
static uint8_t mosfetDuty[5] = {0};

uint32_t piezoFrequency = PWM_DEFAULT_FREQ;
uint8_t  piezoDuty      = 0;
uint16_t expanderState  = 0xFFFF;  // all HIGH = all CS deasserted
bool     expanderOk     = false;
uint8_t  expanderAddr   = I2C_EXPANDER_ADDR;

// I2C health tracking / self-healing. EMI events (ESC/MOSFET switching, ground
// bounce) can corrupt a transaction and leave the bus or the PCF8575 wedged —
// detect it, clock the bus free, and rewrite the expander state automatically.
static uint32_t      i2cFailCount    = 0;
static uint32_t      i2cRecoverCount = 0;
static unsigned long i2cLastRecoverMs = 0;
static bool          tcEverValid     = false;
#define I2C_CLOCK_HZ  100000   // 100 kHz: much better noise margin than 400 kHz
String   commandBuffer  = "";
// Stream on by default: the DevKit auto-resets whenever the EXE opens the COM
// port, so telemetry must flow without a handshake.
bool     streamEnabled  = true;

// TC decode mode: MAX31855 (32-bit, signed 14-bit) or MAX6675 (16-bit, unsigned 12-bit)
static bool tcMode6675 = false;

// Serial2 (Pixhawk) bridge — non-blocking, binary-safe
static uint8_t  s2Buf[64];
static uint8_t  s2Len = 0;
static uint32_t s2LastByteMs = 0;
static bool     s2HexMode = false;
// TELEM1 baud. The Cube's factory default is 57600, but on this rig 115200 is
// the rate that links reliably, so that's our default (set SERIAL1_BAUD=115 on
// the Cube to match). Change live with "px baud <rate>".
#define PIXHAWK_TELEM_BAUD 115200
static uint32_t serial2Baud = PIXHAWK_TELEM_BAUD;

// Digital pot tracked wiper position (0..POT_STEPS-1). Reset to 0 at boot.
static int potPosition = 0;

// CAN state
static bool     canOk       = false;
static uint32_t canKbps     = CAN_DEFAULT_KBPS;
static uint32_t canRxCount  = 0;
static uint32_t canTxCount  = 0;
static bool     canPrintRx  = false;  // DroneCAN is chatty; enable for debug only

// Decoded ESC telemetry (Hargrave microDRIVE via DroneCAN)
struct EscTelemetry {
  bool     seen;
  uint32_t lastMs;
  uint8_t  srcNode;
  uint32_t errorFlags;   // Hargrave custom bitfield in the error_count slot
  float    voltage;      // V
  float    current;      // A
  float    tempC;        // bridge temperature, converted from Kelvin
  int32_t  rpm;
  uint8_t  powerPct;
  uint8_t  escIndex;
  // From StatusExtended (1036)
  bool     extSeen;
  uint32_t extLastMs;
  uint8_t  inputPct;
  uint8_t  outputPct;
  int16_t  motorTempC;
  uint32_t statusFlags;
};
static EscTelemetry esc = {};

// Shaft RPM to use everywhere. DroneCAN's ESC Status caps RPM at int18 (131071);
// past that we switch to a throttle→RPM model (100% = 150k). See updateEscRpm().
static int32_t escRpmExt = 0;

// Hargrave error_count bitfield names (bits 0-12), from the microDRIVE docs
static const char *escErrorNames[13] = {
  "OVER_TEMP", "BUS_OVERCURRENT", "PHASE_OVERCURRENT", "OVER_VOLT", "UNDER_VOLT",
  "RIPPLE", "SIGNAL_LOSS", "MOTOR_SATURATED", "MOTOR_OVER_TEMP", "RPM_LIMIT",
  "ERROR_ACTIVE", "OUTPUT_SHORTED", "STARTUP_CHECK_FAIL"
};

// Latest NodeStatus heartbeat on the bus (any node — normally just the ESC)
static struct {
  bool     seen;
  uint8_t  src;
  uint32_t uptimeSec;
  uint8_t  health;   // 0 OK, 1 WARNING, 2 ERROR, 3 CRITICAL
  uint8_t  mode;     // 0 OPERATIONAL, 1 INIT, 2 MAINTENANCE, 3 SW_UPDATE, 7 OFFLINE
  uint32_t lastMs;
} nodeHb = {};

// Anonymous frames (source node id 0) = a node begging for dynamic node ID
// allocation. If this counts up, the ESC has NO node id and will never send
// telemetry until an allocator (autopilot / GUI tool) assigns one.
static uint32_t anonFrameCount = 0;

// Dynamic node ID allocation server state. We are the only bus master, so the
// ECU plays allocator: collect the requester's 16-byte unique ID over up to
// three anonymous messages, then grant it a node ID.
static struct {
  uint8_t       uid[16];
  uint8_t       len;
  unsigned long lastMs;
  uint8_t       lastGrantedId;
  uint32_t      grants;
} dna = {};

static uint8_t allocTxTid = 0;   // transfer id counters per broadcast type
static uint8_t nsTxTid    = 0;
static uint8_t armTxTid   = 0;
static uint8_t svcTxTid   = 0;   // service request transfer id

// ESC arming. The microDRIVE has CAN_ARM_CHK_EN=1: it refuses to drive the
// motor unless someone broadcasts uavcan.equipment.safety.ArmingStatus =
// FULLY_ARMED within its ARM_MSG_TIMEOUT (1 s). We broadcast the current arm
// state at 2 Hz, and while armed with no active command we stream zero duty
// (REQ_ZERO_THR=1 wants a zero before any nonzero throttle).
static bool escArmed = false;
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
void loop() {
  sensorTask();
  currentSensorTask();
  engineTick();
  ecuHeartbeat();
  processSerialCommands();
  processSerial2Bridge();
  pxTask();
  processCanRx();
  updateEscRpm();       // extend shaft RPM past the ESC's int18 cap
  canThrottleTask();
  nodeStatusTask();
  armingStatusTask();
  paramTask();
  delay(1);
}

// Continuous thermocouple sampling at the MAX31855's conversion rate.
// The stream sender just reports the latest cached values, so raising the
// stream rate never adds SPI/I2C traffic.
void sensorTask() {
  static unsigned long lastTcSample = 0;
  unsigned long now = millis();
  if (now - lastTcSample >= TC_SAMPLE_MS) {
    lastTcSample = now;
    readAllThermocouples();

    // Self-healing: recover the I2C bus if the expander stopped ACKing, or if
    // every channel suddenly returns no SPI data after having worked before
    // (a wedged expander leaves all CS lines stuck, killing all 4 at once).
    bool allDead = true;
    bool anyValid = false;
    for (uint8_t i = 0; i < 4; i++) {
      if (tcRaw[i] != 0x00000000 && tcRaw[i] != 0xFFFFFFFF) allDead = false;
      if (!isnan(tcTemp[i])) anyValid = true;
    }
    if (anyValid) tcEverValid = true;
    if ((!expanderOk || (allDead && tcEverValid)) &&
        now - i2cLastRecoverMs > 1000) {
      i2cLastRecoverMs = now;
      expanderRecover();
    }
  }
}

// -----------------------------------------------------------------------------
// Serial command processing
// -----------------------------------------------------------------------------
void processSerialCommands() {
  while (Serial.available()) {
    char c = Serial.read();
    if (c == '\r') continue;
    if (c == '\n') {
      Serial.println();
      if (commandBuffer.length() > 0) {
        handleLineCommand(commandBuffer);
        commandBuffer = "";
      }
      Serial.print("> ");
      continue;
    }
    if (c == 8 || c == 127) {
      if (commandBuffer.length() > 0) {
        commandBuffer.remove(commandBuffer.length() - 1);
        Serial.print("\b \b");
      }
      continue;
    }
    if (c >= 32 && c <= 126) {
      commandBuffer += c;
      Serial.print(c);
    }
  }
}

// Original-case copy of the current command line. The dispatcher lowercases
// everything, but ESC parameter names (and Serial2 payloads) are case-
// sensitive, so handlers re-extract those tokens from here.
static String cmdOriginalLine;

String nthTokenOf(String line, int n) {
  int p = 0;
  String t;
  for (int i = 0; i <= n; i++) {
    t = getNextToken(line, p);
    if (t.length() == 0) break;
  }
  return t;
}

void handleLineCommand(const String &command) {
  String line = command;
  line.trim();
  if (line.length() == 0) return;

  Serial.print("> ");
  Serial.println(line);

  cmdOriginalLine = line;
  String working = line;
  working.toLowerCase();
  int pos = 0;
  String token = getNextToken(working, pos);

  if (token == "help" || token == "?") {
    printHelp();
  } else if (token == "status") {
    printStatus();
  } else if (token == "mosfet") {
    handleMosfet(working, pos);
  } else if (token == "piezo" || token == "pwm") {
    handlePiezo(working, pos);
  } else if (token == "analog" || token == "adc") {
    handleAnalog(working, pos);
  } else if (token == "tc" || token == "thermocouple" || token == "spi") {
    handleThermocouple(working, pos);
  } else if (token == "current" || token == "amps") {
    handleCurrent(working, pos);
  } else if (token == "pot") {
    handlePot(working, pos);
  } else if (token == "stream") {
    handleStream(working, pos);
  } else if (token == "can") {
    handleCan(working, pos);
  } else if (token == "i2c") {
    handleI2c(working, pos);
  } else if (token == "serial2") {
    handleSerial2(working, pos);
  } else if (token == "px" || token == "pixhawk" || token == "mav") {
    handlePixhawk(working, pos);
  } else if (token == "eng" || token == "engine") {
    handleEng(working, pos);
  } else if (token == "gov") {
    handleGov(working, pos);
  } else if (token == "pump") {
    handlePump(working, pos);
  } else if (token == "glow") {
    handleGlow(working, pos);
  } else if (token == "sol" || token == "solenoid") {
    handleSol(working, pos);
  } else if (token == "ramp") {
    handleRamp(working, pos);
  } else if (token == "thr") {
    handleThr(working, pos);
  } else if (token == "fuel") {
    handleFuel(working, pos);
  } else {
    Serial.println("Unknown command. Type help for a command list.");
  }
}

// =============================================================================
// MAVLink — Pixhawk (Cube Orange) on Serial2 / J21, TELEM1, 115200 8N1
//
// Minimal hand-rolled codec (no external library). Handles both MAVLink v1
// (0xFE) and v2 (0xFD) framing on receive, because ArduPilot may send either
// depending on SERIAL1_PROTOCOL. On transmit we use v1 for msgid < 256 and v2
// for the extended ids (GENERATOR_STATUS = 373) — ArduPilot's parser accepts
// both regardless of what it emits.
//
// RX (what we want from the Pixhawk): barometer + altitude.
// TX (what we give it): our generator/turbine telemetry.
// =============================================================================
#define MAV_STX_V1        0xFE
#define MAV_STX_V2        0xFD
#define PX_OUR_SYSID      1     // same vehicle as the autopilot
#define PX_OUR_COMPID     191   // MAV_COMP_ID_ONBOARD_COMPUTER

#define MAVMSG_HEARTBEAT           0
#define MAVMSG_SYS_STATUS          1
#define MAVMSG_GPS_RAW_INT         24
#define MAVMSG_SCALED_PRESSURE     29
#define MAVMSG_GLOBAL_POSITION_INT 33
#define MAVMSG_REQUEST_DATA_STREAM 66
#define MAVMSG_VFR_HUD             74
#define MAVMSG_COMMAND_LONG        76
#define MAVMSG_ALTITUDE            141
#define MAVMSG_NAMED_VALUE_FLOAT   251
#define MAVMSG_PLAY_TUNE           258
#define MAVMSG_GENERATOR_STATUS    373

// CRC_EXTRA per message (from common.xml). A wrong value here silently drops
// every frame of that type, so these are the verified constants.
static uint8_t mavCrcExtra(uint32_t id) {
  switch (id) {
    case MAVMSG_HEARTBEAT:           return 50;
    case MAVMSG_SYS_STATUS:          return 124;
    case MAVMSG_GPS_RAW_INT:         return 24;
    case MAVMSG_SCALED_PRESSURE:     return 115;
    case MAVMSG_GLOBAL_POSITION_INT: return 104;
    case MAVMSG_REQUEST_DATA_STREAM: return 148;
    case MAVMSG_VFR_HUD:             return 20;
    case MAVMSG_COMMAND_LONG:        return 152;
    case MAVMSG_ALTITUDE:            return 47;
    case MAVMSG_NAMED_VALUE_FLOAT:   return 170;
    case MAVMSG_PLAY_TUNE:           return 187;
    case MAVMSG_GENERATOR_STATUS:    return 117;
    default:                         return 0;   // unknown → we don't decode it
  }
}

// X.25 / CRC-16-MCRF4XX, as used by MAVLink
static void mavCrcAccum(uint8_t b, uint16_t *crc) {
  uint8_t t = b ^ (uint8_t)(*crc & 0xFF);
  t ^= (t << 4);
  *crc = (*crc >> 8) ^ ((uint16_t)t << 8) ^ ((uint16_t)t << 3) ^ ((uint16_t)t >> 4);
}

// little-endian field readers
static uint16_t mavU16(const uint8_t *p) { return (uint16_t)p[0] | ((uint16_t)p[1] << 8); }
static int16_t  mavI16(const uint8_t *p) { return (int16_t)mavU16(p); }
static uint32_t mavU32(const uint8_t *p) {
  return (uint32_t)p[0] | ((uint32_t)p[1] << 8) | ((uint32_t)p[2] << 16) | ((uint32_t)p[3] << 24);
}
static int32_t  mavI32(const uint8_t *p) { return (int32_t)mavU32(p); }
static float    mavF32(const uint8_t *p) { float f; uint32_t v = mavU32(p); memcpy(&f, &v, 4); return f; }

// ---- link + decoded telemetry state ----
static bool     pxEnabled   = true;    // run the MAVLink parser at all
static bool     pxRawEcho   = false;   // dump raw bytes to console (floods! debug only)
static bool     pxGenTx     = true;    // stream our generator data up to the Pixhawk
static uint8_t  pxTxSeq     = 0;
static uint32_t pxGoodFrames = 0, pxBadCrc = 0, pxTxFrames = 0;
// Raw byte counter: counts EVERY byte on Serial2 regardless of framing. This is
// the key wiring diagnostic — if this stays 0 the RX pin is dead (miswire/no
// data); if it climbs but frames don't, it's a baud/protocol problem.
static uint32_t pxRawBytes = 0;
static uint32_t pxLastHbMs  = 0, pxLastMsgMs = 0;
static uint8_t  pxSysId = 0, pxCompId = 0, pxMavVer = 0;
static uint32_t pxLastReqMs = 0;
static bool     pxWasOnline = false;

static float    pxPressAbs = NAN, pxPressDiff = NAN, pxBaroTempC = NAN;
static float    pxAltAmsl = NAN, pxAltRel = NAN, pxClimb = NAN;
static float    pxGroundSpd = NAN, pxAirSpd = NAN, pxVBatt = NAN;
static int16_t  pxHeading = -1, pxBattRem = -1;
static int16_t  pxGpsFix = -1, pxGpsSats = -1;   // -1 = never received
static float    pxGpsHdop = NAN;

#define PX_LINK_TIMEOUT_MS 3000
static bool pxOnline() { return pxLastHbMs && (millis() - pxLastHbMs < PX_LINK_TIMEOUT_MS); }
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

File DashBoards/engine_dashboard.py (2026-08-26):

"""
UMGT Engine Dashboard — engine-run GUI modeled on the LabVIEW
umgt_7thJuly2026.vi front panel, talking to the ESP32 ECU over USB serial.

LabVIEW → ECU mapping:
  ESC PWM 1500-2000us + MotorTone RPM   → DroneCAN duty + esc.Status telemetry
  NI PID Advanced (RPM → throttle)      → firmware governor (gov on/sp/gains)
  Ramp Up/Pause/Ramp Down + Ramp Rate   → firmware ramp machine
  NE-50X / Bronkhorst / Alicat fuel     → 2x KNF pumps on MOSFET PWM (pump 1/2)
  Fuel Shut Off                         → fuel cut latch (pumps forced 0)
  DAQmx thermocouples                   → 4x MAX31855 (TIT, glow, bearing, coil)
  Record + Write Delimited Spreadsheet  → CSV logging in this exe
  (new) auto start/shutdown sequencer + failsafes with editable parameters

Build: pyinstaller --onefile --windowed --name UMGT_Engine engine_dashboard.py
"""

import json
import math
import os
import re
import time
import queue
import threading
import collections
import csv
import tkinter as tk
from tkinter import ttk, scrolledtext, messagebox, filedialog
from tkinter import font as tkfont
import serial
import serial.tools.list_ports

# ── Theme ─────────────────────────────────────────────────────────────────────
BG       = "#13131a"
SURF     = "#1c1c28"
SURF2    = "#24283b"
BORDER   = "#2a2a3d"
TEXT     = "#c0caf5"
TEXT_DIM = "#565f89"
ACCENT   = "#7aa2f7"
GREEN    = "#9ece6a"
RED      = "#f7768e"
YELLOW   = "#e0af68"
CYAN     = "#7dcfff"
PURPLE   = "#bb9af7"
ORANGE   = "#ff9e64"

FONT_MONO    = ("Consolas", 10)
FONT_MONO_MD = ("Consolas", 12, "bold")
FONT_MONO_LG = ("Consolas", 15, "bold")
FONT_MONO_XL = ("Consolas", 22, "bold")
FONT_UI      = ("Segoe UI", 10)
FONT_UI_B    = ("Segoe UI", 10, "bold")
FONT_UI_SML  = ("Segoe UI", 9)
FONT_TITLE   = ("Segoe UI", 11, "bold")

BAUD         = 115200
# throttle thumb-wheel: one full 360 deg turn = this many percent of
# full scale.  Default 5 %, the user can pick anything from 5 % to 15 %
# in the "%/turn" spinbox under the wheel.
SPEED_PCT_PER_REV = 5.0
HB_TIMEOUT_S = 3.5

PARAMS_FILE  = os.path.join(os.path.expanduser("~"), ".umgt_engine_params.json")

# Engine parameter metadata: (name, label, unit) — mirrors firmware "eng params"
PARAM_META = [
    ("glow_temp",     "Glow temp to proceed",   "°C"),
    ("glow_time",     "Glow preheat max",       "s"),
    ("spool_duty",    "Spool throttle",         "%"),
    ("spool_rpm",     "Spool RPM target",       "rpm"),
    ("spool_time",    "Spool timeout",          "s"),
    ("ign_pump",      "Ignition fuel start",    "ml/min"),
    ("ign_ramp",      "Ignition fuel ramp",     "ml/min/s"),
    ("ign_pump_max",  "Ignition fuel max",      "ml/min"),
    ("lightoff_tit",  "Light-off TIT (abs)",    "°C"),
    ("ign_timeout",   "Ignition timeout",       "s"),
    ("warmup_rpm",    "Warmup idle RPM",        "rpm"),
    ("glow_off_tit",  "Glow off above TIT",     "°C"),
    ("tit_max",       "TIT max (fault)",        "°C"),
    ("coil_max",      "Coil max (fault)",       "°C"),
    ("bearing_max",   "Bearing max (fault)",    "°C"),
    ("max_rpm",       "Max RPM (fault)",        "rpm"),
    ("flameout_tit",  "Flameout TIT floor",     "°C"),
    ("esc_loss",      "ESC loss timeout",       "s"),
    ("cool_duty",     "Cooldown throttle",      "%"),
    ("cool_tit",      "Cooldown until TIT",     "°C"),
    ("cool_time",     "Cooldown max time",      "s"),
    ("pump1_cal",     "Pump 1 flow @100%",      "ml/min"),
    ("pump2_cal",     "Pump 2 flow @100%",      "ml/min"),
    ("fuel_density",  "Fuel density",           "g/ml"),
    ("gov_kc",        "PID Kc",                 "%/rpm"),
    ("gov_ti",        "PID Ti",                 "min"),
    ("gov_td",        "PID Td",                 "min"),
    ("gov_min",       "PID output min",         "%"),
    ("gov_max",       "PID output max",         "%"),
    ("gov_slew",      "Throttle slew limit",    "%/s"),
    ("ramp_rate",     "Ramp rate",              "%/s"),
    ("batt_min",      "Battery 0% voltage",     "V"),
    ("batt_max",      "Battery 100% voltage",   "V"),
    ("sol_duty",      "Solenoid ON duty",       "%"),
]

# Signals that any chart can plot (name, color). The value for each is computed
# fresh every DATA frame in _parse_data → self._sig.
CHART_SIGNALS = [
    ("RPM",              CYAN),
    ("ESC Power [W]",    GREEN),
    ("TIT [°C]",         ORANGE),
    ("EGT / Glow [°C]",  YELLOW),
    ("Bearing [°C]",     GREEN),
    ("Coil [°C]",        PURPLE),
    ("DC Voltage [V]",   GREEN),
    ("DC Current [A]",   YELLOW),
    ("ESC Temp [°C]",    ORANGE),
    ("Battery [%]",      GREEN),
    ("Bus Current [A]",  YELLOW),
    ("Sensor CM [V]",    CYAN),
]

# Signals plotted on the Pixhawk page (fed from the PX_* stream keys)
PX_SIGNALS = [
    ("Altitude AMSL [m]",  GREEN),
    ("Altitude rel [m]",   CYAN),
    ("Pressure [hPa]",     YELLOW),
    ("Baro Temp [°C]",     ORANGE),
    ("Climb [m/s]",        PURPLE),
    ("Ground Speed [m/s]", ACCENT),
    ("Fuel Flow [ml/min]", CYAN),
    ("Throttle [%]",     ACCENT),
]
SIGNAL_COLOR = {name: color for name, color in CHART_SIGNALS}
SIGNAL_NAMES = [name for name, _ in CHART_SIGNALS]

ENG_STATE_COLORS = {
    "OFF": TEXT_DIM, "MANUAL": CYAN, "PRECHECK": YELLOW, "GLOW": ORANGE,
    "SPOOL": ORANGE, "IGNITION": ORANGE, "WARMUP": YELLOW,
    "RUNNING": GREEN, "COOLDOWN": CYAN, "FAULT": RED,
}

CSV_FIELDS = ["time", "elapsed_s", "state", "fault", "rpm", "tit_c", "glow_c",
              "bearing_c", "coil_c", "esc_v", "esc_i", "esc_w", "esc_temp_c",
              "throttle_pct", "gov_on", "gov_sp", "pump1_pct", "pump2_pct",
              "fuel_mlmin", "glow_on", "battery_pct", "bus_current_a", "sensor_cm_v"]
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

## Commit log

2026-06-07 added pin assign
2026-06-11 added correct mosfet control
    [main.ino.cpp]
2026-06-28 added kicad files
    [ESPSheild.kicad_pcb, ESPSheild.kicad_sch]
2026-07-07 fixed code added new models
    [Box_cover_owen.step, box_body_owen.step]
2026-07-12 new bom
    [ECU BOM for 1 ECU complete.xlsx]
2026-07-12 added new 3d models
    [Box_cover_owen.step, BoxbottomIGES.iges, BoxtopIGES.iges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]
2026-07-14 added solenoid support 6v
2026-07-14 cnaged bom
    [ECU BOM for 1 ECU complete.xlsx]
2026-07-21 added another wiring diagram
2026-07-26 Add Pixhawk MAVLink page, draggable columns, SSA-2 sensor UI
    engine_dashboard:
    - New "Pixhawk" tab: barometer/altitude readouts, MAVLink link status +
    frame/raw-byte counters, generator-telemetry TX controls, trend charts
    - Draggable column dividers (PanedWindow) so panels can be resized;
    lower min window size (1040x660) to fit laptop screens
    - Fixed-size gauges + full-width Engine Data strip (no layout shake)
    - SSA-2 differential current sensor relabel (Bus Current / Sensor CM)
    ecu_dashboard:
    - SSA-2 differential current sensor relabel
    Rebuild dist exes.
    [ecu_dashboard.py, engine_dashboard.py]
2026-07-27 Add px beep: play Pixhawk buzzer (PLAY_TUNE) as a link test
    - firmware: px beep [tune] sends MAVLink PLAY_TUNE (id 258) to the Cube;
    verified against pymavlink. Proves the ECU->Cube TX path end to end.
    - engine_dashboard: Beep Cube button on the Pixhawk page.
    [engine_dashboard.py, main.ino.cpp]
2026-07-27 Pixhawk: GPS good/weak/bad indicator, 115200 default, chart-freeze fix
    - firmware: decode GPS_RAW_INT (fix/sats/HDOP) → PX_FIX/PX_SATS/PX_HDOP,
    request it at 2 Hz; default TELEM1 baud 57600 → 115200 (the rate this rig
    links at); 2 KB Serial2 RX buffer; px beep (PLAY_TUNE) link test. All
    MAVLink verified against pymavlink.
    - engine_dashboard: GPS card (GOOD/WEAK/BAD by fix+sats+HDOP); baud default
    115200; fix Pixhawk-page trend charts never being redrawn (they only
    repainted on resize and looked frozen).
    [engine_dashboard.py, main.ino.cpp]
2026-07-28 Coil TC noise filter + RPM model past the int18 cap
    - Coil (TC4) filter: running median (15) + slew-limit (2.5 C/sample) + fault
    hold, since that TC sits inside the motor and picks up heavy EMI. Only the
    coil channel is filtered; tunable live with "tc filter <n>".
    - Shaft RPM past the ESC's DroneCAN int18 cap (131071): below the cap use the
    measured RPM, at/above it switch to a throttle->RPM model fitted from bench
    data, RPM = 2940.21*throttle - 1094 (R^2 = 0.993). Seamless handoff at ~45%
    throttle; feeds gauge, log, governor and Pixhawk SHAFTRPM.
    [main.ino.cpp]
2026-07-29 new wiring diagram
2026-08-17 Added to Solenoid-1 option to be NC instead NO
    [ECU BOM for 1 ECU complete.xlsx]
2026-08-26 Change the Throttle Scroll Bar to Wheel for Engine Protection from Sudden fas turning on ...
2026-08-26 1. I have modified the UMGT Engine Dashboard Software a. Added Help b. Added a new TAB for reading/writing from/to the ESC via CAN Bus c. Added an option to Read/Write/DumpAll Internal Parameters d. 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
    [BoxbottomIGES.iges, BoxtopIGES.iges, ECU BOM for one ECU.xlsx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]
2026-08-26 Fixed the SPEC files and the Build to EXE Scripts
    [ecu_dashboard.py]
2026-08-31 Added BOM to the RPMSensor PCB
    [Order from DigiKey (31.8.2026).xlsx, RPMDRIVER-BOM.xlsx]
2026-09-16 Built New Box and Cover
    [Assem1.SLDASM, BoxbottomIGES.iges, BoxtopIGES.iges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]
2026-09-16 enlarged 4 TEC holes
    [UMGT-Box-2.SLDPRT, UMGT-Box-2.STL]
2026-10-07 modified the holes in the Box and Cover to 5mm
    [UMGT-Box-2.SLDPRT, UMGT-Box-2.STL, UMGT-Cover-2.SLDPRT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]
2026-10-21 There was an issue when dissconnecting the USB Cable while the Dashboard SW is runnig, this causes to a stuck of the DashBoard, the only way to close it is by END-TASK. The Issue was fixed.
